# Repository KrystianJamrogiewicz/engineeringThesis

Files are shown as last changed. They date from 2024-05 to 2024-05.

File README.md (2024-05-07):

# Design and implementation of an unmanned aerial vehicle based on the ESP8266 microcontroller

The engineering thesis is based on the design and construction of an unmanned aerial vehicle in the form of a quadrocopter, using a microcontroller from the ESP8266 family. The theoretical part concerns the principle of operation of multicopters, and also presents the basic components from which they are built. The principles that guided the selection of individual components were discussed there. Next, the computer software that contributed to the project is described. The part devoted to the control system describes the aspects of designing and then implementing the electrical system, as well as the process of creating software controlling the system. The mechanical layout chapter focuses on designing and building the frame, putting all the components together, and testing the finished model. Finally, a partially working prototype of the unmanned aerial vehicle was created. The analysis of the results is discussed in the summary, as well as in the quadrocopter test section.

<p align="center"> drone photo </p>

Technologies:
- Arduino IDE
- C programming
- Autodesk Inventor
- Autodesk Eagle

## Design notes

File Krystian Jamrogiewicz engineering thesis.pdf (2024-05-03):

UNIWERSYTET RZESZOWSKI
Kolegium Nauk Przyrodniczych

Krystian Jamrogiewicz

Nr albumu: 114403

Mechatronika

Projekt i wykonanie bezzałogowego statku latającego w oparciu o mikrokontroler ESP32

Praca inżynierska

Praca wykonana pod kierunkiem

dr Mariusza Bestera

Rzeszów, 2023

## SPIS TREŚCI

## WSTĘP

Bezzałogowe statki latające już w latach trzydziestych XX wieku były określane przez

armię USA jako drony. Drony są sterowane zdalnie lub za pomocą zaprogramowanej

trajektorii. Aktualnie wykorzystywane są zarówno podczas obserwacji jak i wykonywania

różnych czynności w miejscach gdzie człowiek byłby narażony na niebezpieczeństwo [7].

Pierwszy bezzałogowy statek latający powstał w 1935 roku i był sterowany za pomocą

nadajnika radiowego. Dron szybko zainteresowało armię USA, początkowo konstrukcje

tego typu pełniły funkcję celów szkoleniowych dla obrony przeciwlotniczej. Z czasem

zaczęły pełnić funkcje samolotów, a ich zadaniem było zbieranie danych i fotografowanie

obszarów, do których bezpośredni lot załogowym samolotem lub helikopterem byłby

niemożliwy lub zbyt niebezpieczny [5, 7].

W Polsce formalnie drony określa się jako bezzałogowe statki latające (BSL), w

przestrzeni międzynarodowej wykorzystuje się częściej skrót UAV (z angielskiego:

Unmanned Aerial Vehicle) lub UAS (z angielskiego: Unmanned Aircraft System).

Podobnie jak większość zaawansowanych technologii, tak drony początkowo były

bardzo drogie w produkcji. Natomiast od kilku lat, dzięki dynamicznemu rozwojowi

elektroniki, zaczęły powstawać drony w formie wielowirnikowców. Wielowirnikowce w

celu uzyskania siły nośnej korzystają z wielu wirników (śmigieł). Dzięki możliwości

zawiśnięcia w powietrzu są stosowane głównie w celach fotograficznych, a także niekiedy

transportują lżejsze obiekty w trudno dostępne miejsca. Bezzałogowe statki latające w

formie wielowirnikowców w literaturze technicznej określa się również jako koptery lub

multikoptery, w tej pracy inżynierskiej będą wykorzystywane właśnie takie terminy [5, 10,

15].

## CEL I ZAŁOŻENIA PROJEKTU

Celem pracy inżynierskiej jest zaprojektowanie i wykonanie bezzałogowego statku

latającego w formie wielowirnikowca bazując na układzie ESP32. Praca będzie opierać się

na przedstawieniu teorii działania wielowirnikowca, dobraniu podzespołów potrzebnych

do jego wykonania, zaprojektowaniu i wykonaniu układu elektronicznego, a także

oprogramowania umożliwiającego zdalne sterowanie układem. Całość będzie dopełniona

o zaprojektowanie oraz wykonanie ramy multikoptera, rozmieszczeniu na niej wyżej

wymienionych elementów oraz przeprowadzeniu testów całości. Zakłada się wykonanie w

pewnym stopniu działającego prototypu bezzałogowego statku latającego, poznanie jego

możliwości, oraz przeanalizowanie uzyskanych wyników.

## 1. CZĘŚĆ TEORETYCZNA

Profesjonalnie produkowane wielowirnikowce są sterowane za pomocą fal

radiowych. Standardem zaczyna być technologia FPV (z angielskiego: First Person View)

umożliwia ona podgląd na żywo obrazu z kamery zamontowanej na multikopterze przy

użyciu np. smartfonu. Transmisja obrazu odbywa się za pośrednictwem radiowego

przesyłania danych. Klasyfikacja konstrukcji wielowirnikowców opiera się głównie o liczbę

ramion na których zamontowane są zespoły napędowe (silniki wraz ze śmigłami).

Najpopularniejsze z nich to: trikoptery – trzy zespoły napędowe kwadrokoptery – cztery

zespoły napędowe, heksakoptery – sześć zespołów napędowych [15, 16].

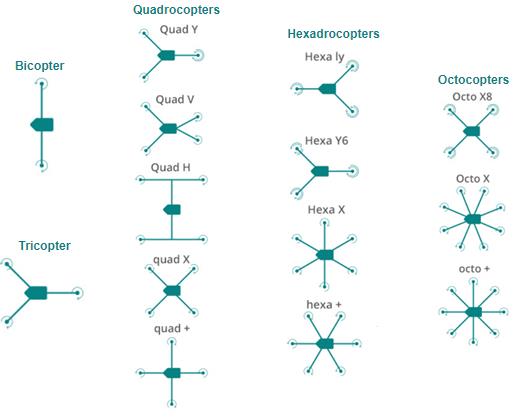
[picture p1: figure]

Rys. 1.1. Rodzaje konstrukcji wielowirnikowców [16]

Konstrukcja z większą liczbą ramion pozwala na bardziej stabilny lot, natomiast

podwójne zespoły napędowe montowane na mniejszej liczbie ramion (np. Y, X8) zwiększają

siłę ciągu, umożliwiając większy udźwig i ubezpieczając równoległy zespół napędowy na

wypadek awarii. Najbardziej rozpowszechnione są koptery w układzie X ponieważ

umożliwiają montaż kamery w miejscu o najlepszej widoczności [16]. Praca inżynierska

zostanie zrealizowana w oparciu o konstrukcje kwadrokoptera typu X

Aby w ogóle wielowirnikowiec był w stanie zawisnąć podczas lotu i nie obracać się w

niekontrolowany sposób wokół własnej osi stosuje się pary zespołów napędowych, które

obracają się w przeciwnych kierunkach, będzie to omówione szerzej w podrozdziale

dotyczącym śmigieł. W celu uzyskania kontrolowanego obrotu „yaw” należy zmniejszyć ciąg

powietrza dla jednej pary a zwiększyć dla drugiej, pozwala to na uzyskanie efektu obrotu

bez strat na wysokości. Podczas swobodnego zwisu wielowirnikowca konieczne jest takie

sterowanie ciągiem zespołów napędowych aby kompensowały one jego przechylenia. Zbyt

duże przechylenie doprowadzi do obrócenia się obiektu śmigłami w dół i jego upadku. Ruch

do przodu, do tyłu „pitch” oraz na boki „roll” jest realizowany poprzez przechylenie

kwadrokoptera w oparciu o zmniejszenie lub zwiększenie ciągu zespołów napędowych.

Przykładowo ruch do przodu odbędzie się poprzez zmniejszenie ciągu w przedniej części

multikoptera a zwiększenie w tylnej, uzyska się wtedy efekt pochylenia do przodu co

zapewni siłę pchającą skierowaną w kierunku pochylonej niżej strony. Cały proces

sterowania poszczególnymi zespołami napędowymi jest realizowany przez kontroler lotu.

Rys. 1.2. Kierunki obrotu śmigieł dla kwadrokopterów [17]

Rys. 1.3. Rodzaje ruchu dla kwadrokoptera typu + [17]

### 1.1. Środowisko sprzętowe

Ten podrozdział został poświęcony opisowi urządzeń oraz części wykorzystanych

podczas wykonania projektu inżynierskiego. Poruszone zostaną zasady wyboru poszczególnych podzespołów z uwzględnieniem ich parametrów technicznych. Znajdą się

w nim informację na temat: zespołów napędowych, regulatorów prędkości, kontrolera

lotu, urządzenia odczytującego położenie, oraz źródła zasilania.

### 1.1.1. Śmigła i silniki

Śmigła i silniki są głównymi systemami napędowymi multikoptera i odgrywają

decydującą rolę. Elementy te poddawane są największym obciążeniom spośród wszystkich

komponentów multikoptera. Z wszystkich podzespołów składających się na całość modelu

latającego parametry śmigieł oraz silników powinny zostać dobrane w pierwszej kolejności.

Aby wielowirnikowiec mógł poruszać się w powietrzu stosunek ciągu wszystkich zespołów

napędowych do masy całego obiektu powinien wynosić przynajmniej 2:1. Rozmiar śmigieł

decyduje o rozmiarze wielowirnikowca i to właśnie na nich spoczywa ciężar całej

konstrukcji [15].

Podstawową rolą śmigła jest wytwarzanie ciągu powietrza, czyli siły nośnej działającej w osi śmigła umożliwiającej unoszenie się modelu. Śmigło o większej średnicy będzie

generowało większą siłę nośną niż jego mniejszy odpowiednik przy tej samej prędkości

obrotowej. Cechą większych śmigieł jest większa masa i potrzeba zapewnienia większego

momentu obrotowego do ich napędzenia co skutkuje doborem mocniejszego silnika.

Większe śmigło generuje również większy nacisk na piastę za sprawą większej siły nośnej,

należy pamiętać aby wybierać śmigła możliwie dobrej jakości w celu uniknięcia pęknięcia

śmigła podczas jego wysokich obrotów. Zbyt małe śmigło powoduje częstą pracę silnika na

maksymalnych obrotach, natomiast zbyt duża powierzchnia łopat nadmiernie obciąża silnik

co prowadzi do braku możliwości uzyskania maksymalnego możliwego ciągu. Ilość łopat na

śmigle wpływa na ciąg w podobny sposób co jego średnica. Im więcej będzie łopat (tym

większa ich powierzchnia) tym większą siłę ciągu uda się uzyskać, jednak przełoży się to na

masę śmigła i zwiększone zużycie energii przez silnik. Zaletą takiego rozwiązania jest jednak

kompaktowość konstrukcji ponieważ śmigło o mniejszej średnicy z większą liczbą łopat

może pochwalić się podobnym ciągiem co jego większy odpowiednik z mniejszą ich ilością.

Kolejnym ważnym parametrem jest skok śmigła, można go porównać do skoku gwintu na śrubie. Ściśle zależy on od kąta pochylenia łopat śmigła jednak nie jest tym samym. Skok śmigła to odległość jaką pokonało by śmigło w powietrzu w czasie jednego obrotu gdyby

nie dochodziło do jego poślizgu. Analogicznie dla śruby będzie to odległość jaką pokona

wierzchołek śruby podczas wkręcania jej w gwint przez jeden pełny obrót. Parametry śmigła

podaje się za pomocą jego cechy czyli napisu widocznego na śmigle. Przykładowo

oznaczenie 1045 lub 10x4,5 oznacza, że śmigło ma średnice 10 cali i skok 4,5 cala [6, 12,

15].

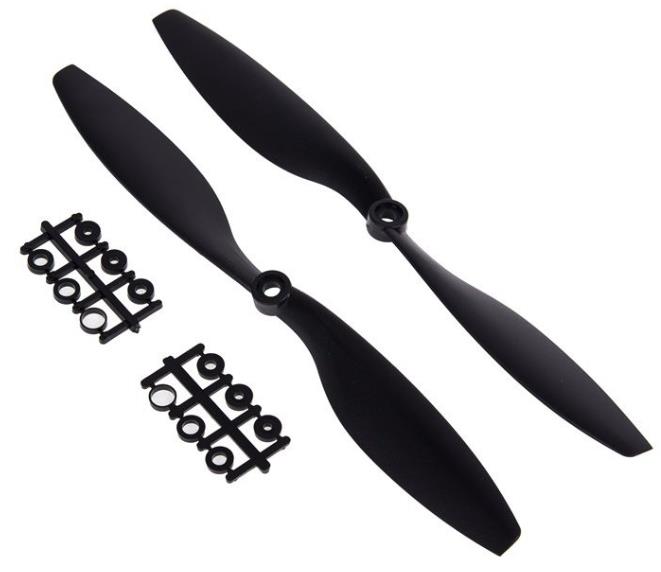
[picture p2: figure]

Rys. 1.4. Śmigła 1045 CW oraz CCW [18]

Podsumowując, im większe śmigło tym większy uzyskany ciąg, im większy skok śmigła

przy tej samej średnicy tym większa będzie prędkość modelu. Dla modelu akrobacyjnego

stosuje się śmigło o większym skoku ponieważ będzie on latał z większymi prędkościami,

modele przeznaczone do celów fotograficznych latające bardzo wolno, którym zależy na

dużej stabilności powinny mieć największą możliwą średnicę śmigła przy możliwie małym

skoku. Istnieje podział śmigieł na prawe oraz lewe, jest to spowodowane naturalnym

zjawiskiem obrotu całego koptera w kierunku ruchu śmigła. Aby pozbyć się tego efektu stosowane są pary silników obracające się w przeciwne strony co skutkuje koniecznością

posiadanie dwóch typów śmigieł, które w obydwu przypadkach muszą zapewnić ciąg

powietrza w odpowiednim kierunku. Wyróżniamy śmigła ciągnące (prawe) obracające się

zgodnie ze wskazówkami zegara oznaczone CW z angielskiego: Clockwise, lub R od regular. Śmigła pchające (lewe) kręcą się w lewą stronę posiadają oznaczenia CCW z angielskiego:

Counter Clockwise - przeciwnie do wskazówek zegara, oraz P – pusher [19].

Tab. 1.1. Zależność ciągu od parametrów śmigła [19]

Do materiałów z których wykonuje się śmigła zaliczamy: poliwęglan, nylon oraz

włókno szklane, oraz wszelkie ich mieszanki. W zależności od materiału użytego w produkcji

śmigła mogą być miękkie (poliwęglan, nylon) lub twarde (włókno szklane). Zaletą śmigieł

miękkich jest duża wytrzymałość na uderzenia, jednak trzeba liczyć się z ich odkształcaniem.

Natomiast śmigła twardsze mają dużo lepsze parametry dotyczące stabilności lotu i brak

jakichkolwiek ugięć, z kolei ich wadą jest możliwość łatwiejszego uszkodzenia podczas

upadku [6, 15, 19].

Silnik elektryczny zamienia energię elektryczną w energię mechaniczną, za pomocą

pola magnetycznego. W opisywanym projekcie ma za zadanie poruszyć śmigło z

odpowiednią prędkością w celu wytworzenia przez nie optymalnego ciągu powietrza. Silniki

wykorzystywane w kopterach dzielimy na szczotkowe oraz bezszczotkowe.

Odmiana szczotkowa często nazywana DC charakteryzuje się zasilaniem przez prąd

stały, zbudowana jest z: wirnika (rotoru), przez który przechodzi wyprowadzona na

zewnątrz oś, uzwojenia nawiniętego na wirnik, stojanu (statoru) zawierającego magnesy

stałe, który otacza wirnik, komutatora, który przełącza uzwojenia na wirniku, oraz

szczotek doprowadzających zasilanie do komutatora. Szczotki są elementem podlegającym

zużyciu na skutek tarcia, ponadto silniki szczotkowe mają mniejszą sprawność niż bez

szczotkowe. Sterowanie obrotami odbywa się poprzez zmianę napięcia zasilającego silnik

[9, 15].

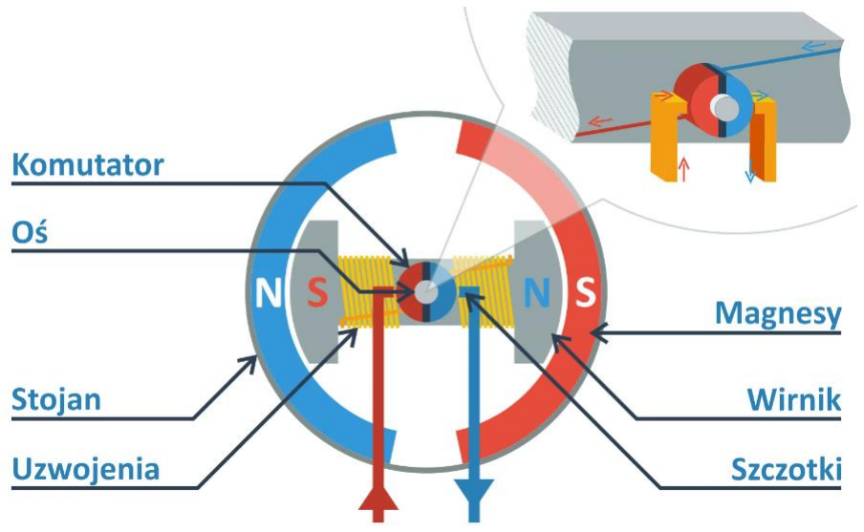
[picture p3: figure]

Rys. 1.5. Budowa silnika szczotkowego [9]

Odmiana bez szczotkowa BLDC jest zbudowana z wirnika (rotoru), na którym

zamocowane są magnesy oraz stojanu inaczej statoru, na którym znajdują się uzwojenia.

Rys. 1.6. Budowa silnika bez szczotkowego [4]

Na podstawie rozmieszczenia tych dwóch komponentów, silniki bez szczotkowe

dzielą się na inrunner „gdzie rotor jest otoczony przez stator” i outrunner „gdzie stator jest

otoczony przez rotor”. W wielowirnikowcach częściej stosowany jest typ outrunner, który

pozwala na uzyskanie większego momentu obrotowego [15].

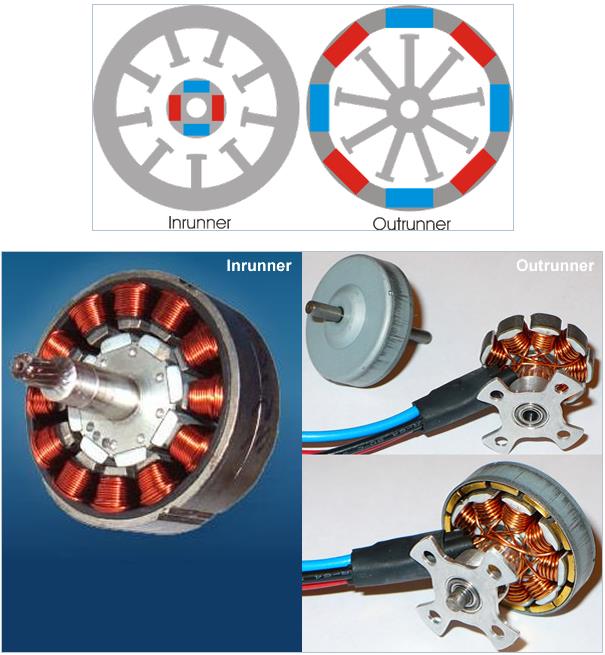
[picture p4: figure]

Rys. 1.7. Budowa silników Inrunner i outrunner [27]

Dzięki prostej budowie i nie posiadaniu elementów podatnych na zużycie silniki

bezszczotkowe górują nad wariantem szczotkowym za sprawą znacznie mniejszej

awaryjność, większej sprawności, oraz możliwością płynniejszej regulacji obrotów. W

konstrukcjach wielowirnikowych wykorzystywane są silniki zasilane prądem trójfazowym,

ich działanie jest niemożliwe bez komutatora którego rolę pełni osobna elektronika zwana

regulatorem ESC. Regulacja prędkości odbywa się przez zmianę częstotliwości przełączania

faz [15].

Najważniejszymi parametrami silnika są: napięcie zasilające podawane w woltach lub

za pomocą parametru S (zostanie omówione w podrozdziale poświęconemu zasilaniu),

maksymalny pobór prądu, maksymalna liczba obrotów na minutę, oraz liczba obrotów na

minutę uzyskana z jednego wolta napięcia zasilania oznaczana jako KV. Im mniejsza jest wartość parametru KV tym mniejsze są maksymalne obroty silnika, jednak rośnie wartość

momentu obrotowego. Dla większych śmigieł stosuje się silniki z mniejszym

współczynnikiem KV [15].

Aby poprawnie dobrać zespół napędowy (śmigło i silnik) należy skorzystać z

informacji dotyczących parametrów silnika najczęściej znajdujących się na stronie sklepu.

Kluczową informacją jest zakres dopuszczalnych rozmiarów śmigieł przewidziany dla tego

silnika.

Tab. 1.2. Parametry doboru śmigieł dla silnika A2212/13T 1000KV [20]

Silnikami i dla projektowanego koptera będą: A2212/13T 1000KV. Z dokumentacji

technicznej wynika, że dla tego typu silników optymalne będą śmigła o wymiarach w

zakresie od 8x4 do 10x8. Silnik powinien być zasilany napięciem 11,1V. Kolumny „Amps”

oraz „Thrust” w powyższej tabeli informują o maksymalnym poborze prądu, oraz

wytworzonym ciągu dla danej prędkości obrotowej oraz rozmiaru śmigła. Z uwagi na łatwą

dostępność dla tego projektu zostaną wybrane śmigła o oznaczeniu 1045.

Wybrany zespół napędowy będzie charakteryzował się: napięciem zasilania 11,1V

maksymalnym poborem prądu równym 13A, oraz maksymalnemu ciągowi około 750g. Z

uwagi na brak danych na temat śmigła o pożądanych wymiarach (1045) parametry zostały

oszacowane na podstawie śmigła (1050) o zbliżonych wymiarach. Dobrze dobrany zespół

napędowy powinien dysponować odpowiednim ciągiem i nie pobierać przy tym olbrzymich

ilości energii.

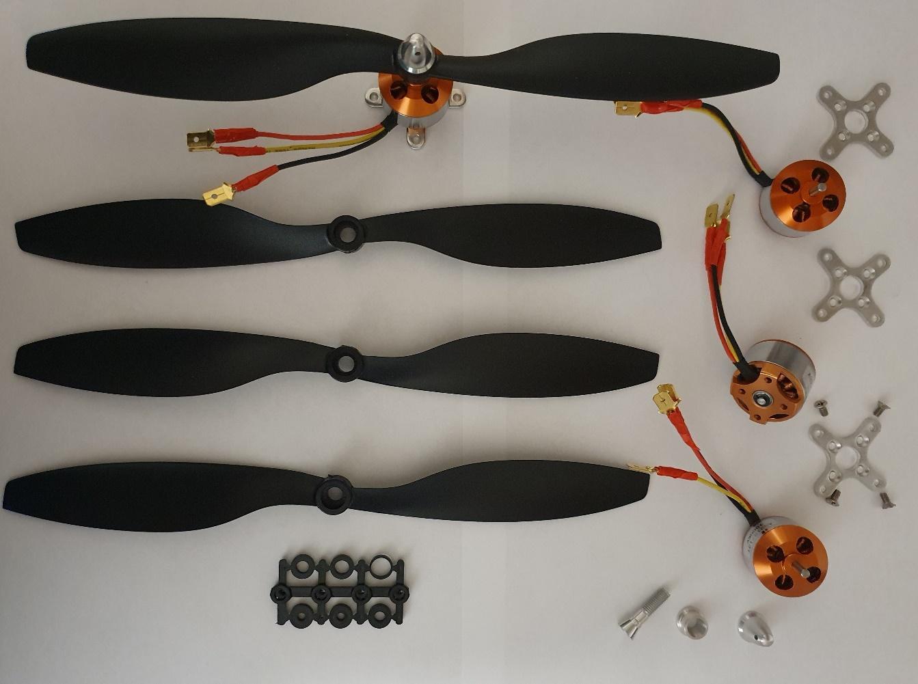
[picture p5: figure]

Rys. 1.8. Śmigła i silniki zastosowane w projekcie

### 1.1.2. Regulatory ESC

Elektroniczna kontrola prędkości ESC - z angielskiego: Electronic Speed Control. Zadaniem regulatorów ESC jest przekazanie energii z baterii do silnika. Na podstawie

sygnału sterującego PWM z kontrolera lotu regulator ESC przekazuje do silnika napięcie

które zapewni mu odpowiednią prędkość obrotową. Głównym podziałem regulatorów jest

ten ze względu na rodzaj obsługiwanego silnika: silniki szczotkowe (2 przewody zasilające

silnik) i silniki bezszczotkowe (3 przewody zasilające silnik). Niektóre Regulatory ESC

posiadają możliwość zasilania urządzeń mniejszym napięciem niż to z baterii, przykładowo

gdy napięcie baterii jest większe niż 6V można zasilać płytkę kontroli lotu napięciem 5V z

odpowiedniego wyprowadzenia regulatora ESC. Regulator który to umożliwia posiada

obwód eliminatora baterii zwany BEC - Battery Elimination Circuit. Kolejnym ważnym

parametrem jest napięcie pracy często wyrażane w liczbie ogniw baterii np.: 2S, 3S, 4S. Ten

aspekt zostanie szerzej omówiony w części poświęconej zasilaniu. Do wcześniej wybranych

śmigieł i silników należy dobrać regulatory ESC o odpowiednim prądzie pracy. Zbyt słaby

regulator może ulec uszkodzeniu, zbyt mocny regulator nie przynosi negatywnego efektu

poza większą wagą i ceną. Regulator powinien być tak dobrany aby jego prąd pracy był o

około od 20% do 30% większy od maksymalnego prądu pobieranego przez silnik z

uwzględnieniem wielkości śmigła. Jeżeli silnik często jest blokowany lub w pełni obciążony

(na przykład w samochodach RC) zalecane jest dobranie regulatora o prądzie pracy bliskim

prądowi szczytowemu silnika [15, 21, 22].

Rys. 1.9. Zastosowany (https://cf.shopee.com.my/file/10e4f0d7d5f3a03d9d0fc844b3e10bfa) w projekcie regulator ESC [23]

Podczas wykonywania tego projektu wybrano regulatory ESC: Brushless 30A 2-4S.

Regulator tego typu może pracować z ciągłym prądem równym 30A i prądem szczytowym

równym 40A. Posiada BEC - możliwość zasilania innych podzespołów napięciem 5V z

maksymalnym prądem 2A. Może pracować z akumulatorami od 2S do 4S.

### 1.1.3. Kontroler lotu

Kontroler lotu jest poniekąd „mózgiem” modelu, który odpowiada za jego

prawidłowe reakcje na wydawane mu polecenia sterujące, oraz czynniki zewnętrzne takie

jak podmuchy wiatru. Dzięki danym wejściowym: pochyleniom i przyspieszeniom

(względem osi: x, y, z), zaprogramowany algorytm kontrolera lotu wyznacza orientacje

multikoptera w przestrzeni. W następnej kolejności ustala odpowiednie prędkości

poszczególnych silników. Profesjonalne kontrolery lotu składają się z mikroprocesora,

żyroskopu i akcelerometru na jednej kompaktowej płytce. Bardziej zaawansowane

konstrukcje posiadają również dodatkowe czujniki i systemy jak: kompas magnetometr,

barometr. Mikroprocesor płytki kontroli lotu powinien być wystarczająco szybki aby podołać wielu skomplikowanym obliczeniom w możliwie najkrótszym czasie. Wolne

procesory mogą być przyczyną nadmiernych korekt podczas lotu [10, 15].

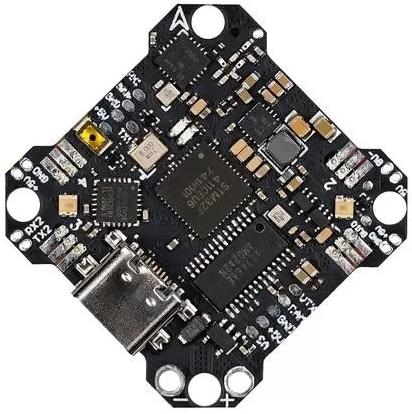
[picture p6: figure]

Rys. 1.10. Kontroler lotu F4 1S 12A AIO V2 (ELRS 2.4G) – BETAFPV [20]

Układ ESP8266 osadzony w płytce NodeMCU v2 jest przykładem mikrokontrolera z

możliwością sterowania sygnałem WiFi. W omawianym projekcie będzie on spełniał funkcję

kontrolera lotu.

ESP8266 jest układem SoC (z angielskiego: System on a Chip) od chińskiego

producenta Espressif Systems. Układ zawiera w sobie elementy niezbędne do komunikacji

przez WiFi w standardzie 802.11 b/g/n pracujących z częstotliwością 2,4 GHz. Posiada

również | wbudowany | stos TPC/IP i | może | działać | w | trybach AP (Access

Point), STA (standalone) oraz AP+STA [2, 8].

NodeMCU v2 jest płytką, która wykorzystuje układ ESP8266 w postaci 22 pinowego

modułu z wbudowanym 32-bitowym układem RISC taktowanym zegarem 80MHz.

Układ wyróżnia się 10 portami GPIO, 2 portami UART oraz jednym 10-bitowym wejściem ADC. Każdy z portów GPIO może być wykorzystany jako PWM, I²
| | | | | | c, SPI lub 1-Wire.

Moduł NodeMCU v2 został wyposażony w stabilizator napięcia 3,3V oraz konwerter USB-

to-UART CP2120, dzięki czemu jest możliwe zasilenie i programowanie płytki bezpośrednio

z portu USB. Programowanie płytki może odbywać się za pomocą języka

skryptowego Lua lub przy pomocy Arduino IDE [2, 8].

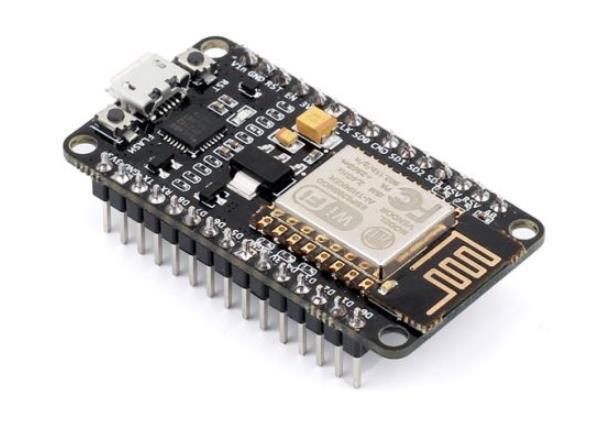
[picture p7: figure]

Rys. 1.11. Płytka NodeMCU v2 [8]

Dane techniczne:

- Moduł zbudowany w oparciu o układ ESP8266-12E z anteną PCB
- Łączność Wi-Fi w standardzie 802.11 b/g/n
- Działa w trybach AP (Access Point), STA (Standalone), AP+STA
- Obsługuje TKIP, WEP, CRC, CCMP, WPA/WPA2, WPS
- Zasilanie: 4,5V - 10V (lub 5V przez port USB)
- Maksymalny pobór prądu: 215mA
- Procesor RISC 80MHz
- 10 portów GPIO - PWM / I2C / SPI / 1-Wire
- Maksymalne natężenie na portach I/O: 12mA
- Konwerter USB-UART - CP2102
- Konwerter ADC - 10-bitowy
- 30 portów w rastrze 2,54mm
- Złącze micro USB
- Wymiary: 49 x 25mm

- Dwa przyciski: FLASH, służący do programowania, oraz RST (RESET)
- Niebieska dioda LED podłączona do GPIO16

Rys. 1.12. Opis wyprowadzeń płytki NodeMCU v2 [28]

### 1.1.4. Żyroskop i akcelerometr

Orientacja multikoptera określa jego pochylenie, przechylenie i odchylenie. Czujniki

potrafiące odczytać orientację to akcelerometry i żyroskopy. Są one umieszczane w taki

sposób, aby mogły mierzyć ruch we wszystkich trzech płaszczyznach. Akcelerometry

odczytują przesunięcia wzdłuż trzech poszczególnych osi (x, y, z, nazywane też

translacjami), podczas gdy żyroskopy mierzą obroty wokół osi pochylenia, przechylenia i

odchylenia. System sterowania powinien być jak najszybszy i najczulszy, aby w porę mógł

zareagować np. na gwałtowny podmuch wiatru. Optymalny efekt można uzyskać stosując

zarówno żyroskop jak i akcelerometr. [10, 15].

Istnieją dwa typy akcelerometrów: piezoelektryczne i pojemnościowe.

Akcelerometry piezoelektryczne są spotykane najczęściej. Zawierają one mikroskopijne

kryształy, które reagują na nacisk, gdy struktura kryształu zostanie odkształcona,

generowany jest prąd elektryczny. Mierząc polaryzację i wielkość tego prądu, system sterowania może ustalić kierunek i prędkość ruchu. W akcelerometrach pojemnościowych

mierzona jest pojemność elektryczna między mikrostrukturami znajdującymi się blisko

czujnika. W miarę jak mikrostruktury te zbliżają się lub oddalają od czujnika, zmienia się

pojemność. Mierząc ją, system sterowania może określić kierunek i prędkość ruchu [15].

Istnieje również kilka rodzajów żyroskopów: kryształowe (których działanie jest

zbliżone do akcelerometrów piezoelektrycznych), ceramiczne (w których wykorzystywane

są miniaturowe ceramiczne kolumny lub pryzmaty) i silikonowe (których budowa różni się

w zależności od producenta) [15].

W projekcie został wykorzystany moduł żyroskopu z akcelerometrem MPU6050.

Zamontowany na płytce modułu układ scalony MPU6050 zawiera struktury MEMS (z

angielskiego: Micro Electro Mechanical Systems) pełniące funkcję półprzewodnikowych

żyroskopów i akcelerometrów. Czujniki układu odgrywające rolę akcelerometrów mierzą

wartość przyspieszenia w 3 osiach, a czujniki żyroskopów mierzą rotację względem tych osi.

Gdy moduł jest ustawiony poziomo i pozostaje w bezruchu, akcelerometr osi Z powinien zmierzyć wartość około 9,81 m/s²
co odpowiada średniemu przyspieszeniu ziemskiemu, natomiast akcelerometry osi X i Y powinny podawać wartości bliskie 0 m/s²
. Odwrócenie

płytki „do góry nogami” skutkuje odczytem wartości ujemnej – 9,81 m/s²
zmierzonej w osi
Z. Każde przesunięcie płytki np. w kierunku +X spowoduje pomiar w tej osi chwilowego

przyspieszenia o wartości dodatniej, proporcjonalnego do prędkości ruchu płytki. Z kolei

w czasie obracania płytki wokół osi żyroskopy zmierzą obrót w jednostkach stopni

kątowych na sekundę [13, 25].

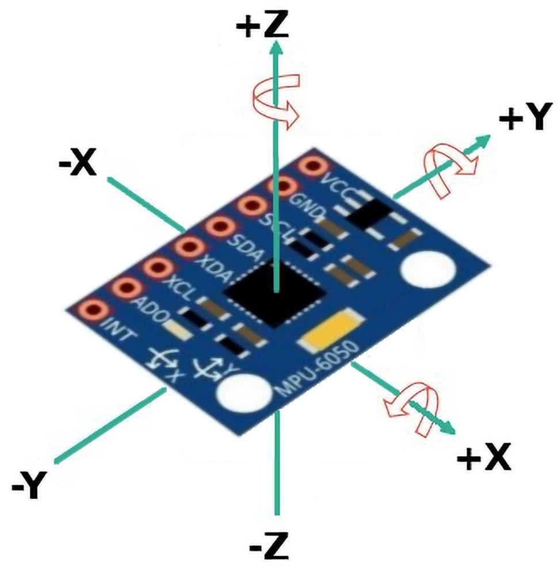
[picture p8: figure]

Rys. 1.13. Opis osi dla modułu MPU6050 [13]

Płytka jest wyposażona w układ stabilizatora LDO pozwalający rozszerzyć

dopuszczalne napięcie zasilania do zakresu 3,3V - 5V. Charakteryzuje się niskim poborem

prądu do około 350µA. Dodatkowo na płytce zamontowano oporniki podciągające linie magistrali I²C do napięcia zasilającego oraz opornik ustawiający na wyprowadzeniu wyboru

adresu AD0 poziom niski. Uzyskiwane w czasie pomiarów sygnały analogowe

akcelerometrów i żyroskopów są poddawane obróbce w wewnętrznych przetwornikach

ADC i jako wartości cyfrowe są dostępne do odczytu z rejestrów układu MPU6050. [13].

Oznaczenia i funkcje wyprowadzeń:

- VCC – napięcie zasilające 3,3...5 V
- GND – masa zasilania
- SCL – linia zegarowa magistrali I2C podciągnięta do VCC
- SDA – linia danych magistrali I2C podciągnięta do VCC
- XDA – linia danych dodatkowej niezależnej magistrali I²C
- XCL – linia zegara dodatkowej niezależnej magistrali I²C
- ADO – wejście wyboru adresu, na który będzie reagował moduł w obrębie głównej magistrali I²C (dla poziomu niskiego będzie to adres 0x68, dla poziomu wysokiego (3,3 V) 0x69. Linia jest podciągana do poziomu niskiego poprzez opornik na płytce modułu)

- INT – wyjście przerwania, może być zaprogramowana do wystawiania stanu niskiego w przypadku wystąpienia zdarzenia np. przekroczenia poziomu przyspieszenia

### 1.1.5. Zasilanie

Istnieje wiele typów akumulatorów jednak multikoptery najczęściej są zasilane za

pomocą wariantów litowo polimerowych (Li-Po). Ten typ akumulatora ma najlepszy

stosunek masy do energii jaką magazynuje. Składa się z jednego lub kilku połączonych

ogniw (cel). Ogniwo Li-Po jest zbudowane ze stopów litu i polimerów o właściwościach

przewodzących, zwykle w postaci stałej lub żelu, jak standardowe ogniwa posiada anodę

oraz katodę. Napięcie pracy pojedynczego ogniwa mieści się w zakresie od 2,75V do 4,2V.

Do poprawnej eksploatacji akumulatora Li-Po niezbędne będzie używanie specjalnych

ładowarek z balanserem, które dostarczają takie samo napięcie do każdego ogniwa, należy

pamiętać, by ładowarka nie ładowała akumulatora prądem większym niż jego maksymalny

prąd ładowania. Aby cieszyć się długim działaniem akumulatora nie należy dopuszczać do

rozładowania się pojedynczych ogniw poniżej napięcia 3V. W celu długotrwałego

przechowywania akumulatora należy naładować pojedyncze ogniwa do napięcia od 3,7V

do 3,8V [15].

Rys. 1.14. Akumulator zastosowany w projekcie [29]

Napięcie znamionowe jest podstawowym parametrem akumulatora, jego wielkość

musi mieścić się w zakresie napięć obsługiwanych przez silniki. Jest podawane w woltach,

lub za pomocą parametru S. Liczba stojąca przed S określa z ilu ogniw (cel) składa się

akumulator, przykładowo 3S oznacza, że akumulator jest zbudowany z 3 ogniw. Biorąc pod

uwagę, że napięcie znamionowe jednego ogniwa wynosi 3,7V to akumulator 3S będzie miał

napięcie znamionowe równe: 3 × 3,7V = 11,1V [15].

Pojemność akumulatora wyrażona w mAh (miliamperogodzinach) określa jak duży

prąd przez określony czas można pobrać z w pełni naładowanego akumulatora aby go w

pełni rozładować. Im większa pojemność tym akumulator będzie mógł dłużej zasilać

odbiorniki, jednak wraz ze wzrostem pojemności zwiększają się rozmiary i masa

akumulatora [15].

Wydajność prądowa, określana parametrem C jest to maksymalne natężenie prądu

jakie można pobrać z akumulatora. Oblicza się ją poprzez mnożenie liczby stojącej przed C

oraz pojemności akumulatora. Przykładowo akumulator o pojemności 2200mAh i

oznaczeniu 30C będzie cechował się następującą wydajnością prądową:

Zamiana na jednostki SI: | 2200mAh = 2,2Ah
Wydajność prądowa: | 2,2Ah × 30 = 66A

Stosuje się także oznaczenia np.: 30C-40C, pierwsza cyfra (30) to współczynnik dla ciągłej

wydajności prądowej, a druga (40) dla chwilowej, co oznacza, że przez krótką chwilę

akumulator może osiągnąć większą wydajność prądową bez jego uszkodzenia [15].

Dobrze dobrany akumulator musi być w stanie zaspokoić zapotrzebowanie prądowe

dla wszystkich zespołów napędowych oraz innych podzespołów multikoptera. Zbyt mała

wydajność prądowa doprowadzi do uszkodzenia akumulatora oraz nie uzyskania

maksymalnego możliwego ciągu przez zespół napędowy.

Parametry odbiorników:

Zespół napędowy:

Napięcie zasilania silnika: 11,1V

Maksymalny pobór prądu dla jednego silnika: 13A

Maksymalny pobór prądu dla wszystkich silników: 13A × 4 = 52A

Kontroler lotu:

Napięcie zasilania: 4,5V – 10V

Maksymalny pobór prądu = 215mA = 0,215A

Żyroskop / akcelerometr:

Napięcie zasilania: 3,3V – 5V

Maksymalny pobór = 350µA = 0,00035A

Maksymalny pobór prądu całego układu = 52A + 0,215A + 0,00035A = 52,21535A

Napięcie zasilania całego układu będzie wynosić 11,1V ponieważ właśnie takiego

wymagają silniki, Kontroler lotu oraz żyroskop / akcelerometr będą zasilane napięciem 5V

przekonwertowanym z 11,1V przez regulatory ESC.

Maksymalny pobór prądu całego układu będzie wynosił około 52,21535A. Dla

bezpieczeństwa wydajność prądowa akumulatora powinna być przynajmniej 1A większa niż

obliczony pobór całego układu. Znając maksymalny pobór prądu można oszacować czas

lotu. Teoretycznie dla akumulatora o pojemności 2200mAh obciążenie pobierające prąd

2200mA rozładuje go w pełni po upływie godziny. Jednak w praktyce akumulatory Li-Po aby

nie doznać uszkodzenia nie mogą być rozładowywane poniżej 20% ich pojemności.

Szacowanie czasu pracy dla obciążenia 53A i pojemności 2200mAh:

Pojemność akumulatora = 2200mAh = 2,2Ah

Zmniejszenie pojemności o 20%: 2,2 × 0,8 = 1.76Ah

Czas pracy akumulatora wyraża się wzorem:

t = Cp / Ir

gdzie:

t – czas pracy w godzinach

Cp – pojemność akumulatora

Ir – prąd pobierany przez odbiorniki

Cp = 1,76Ah

Ir = 53A

t = 1,76Ah / 53A = 0.0332075471698113h ≈ 120s = 2min

Czas pracy podczas poboru 53A wynosi 2 min. Należy pamiętać, że przyjęty pobór

prądu jest oszacowany dla silników kręcących się z maksymalną prędkością, a czas

przeciętnego lotu powinien potrwać nieco dłużej. Aby dokładniej oszacować czas lotu

należy obliczyć uśrednioną wartość poboru prądu.

Wybór odpowiedniego akumulatora dla projektu:

Wymagany będzie akumulator o napięciu znamionowym 11,1V i wydajności

prądowej większej niż 53A. Dla danego układu zastosowane będzie źródło zasilania typu Li-

Po firmy Redox o oznaczeniach: 3S 2200mAh 30C. Posiada ono napięcie znamionowe 11,1V,

pojemność 2200mAh, oraz wydajność prądową równą 66A. Jego masa to 150 g a wymiary:

103 x 34 x 20 mm. Oszacowany czas lotu na jednym ładowaniu będzie nie mniejszy niż 2

minuty. Dla projektu o tych parametrach bardziej zalecany byłby akumulator o większej

pojemności zapewniający dłuższy czas lotu, jednak z powodu dostępności oraz testowego

przeznaczenia projektu zostało wybrane po wyższe źródło zasilania.

### 1.2. Środowisko programowe

W tym podrozdziale zostały omówione oprogramowania oraz aplikacje wykorzystane

podczas wykonania pracy inżynierskiej. Znajdą się w nim informację na temat

oprogramowania służącego do programowania mikrokontrolerów, aplikacji która posłużyła

do sterowania urządzeniem, a także programów używanych do projektowania obwodu

elektrycznego, oraz modelowania 3D.

### 1.2.1. Arduino IDE

Arduino IDE (z angielskiego: Integrated Development Environment) jest otwartym

środowiskiem programistycznym, które upraszcza proces pisania kodu i pozwala przesłać

go na płytki z rodziny Arduino. Otwarty kod źródłowy - open source umożliwia ciągłe

udoskonalanie środowiska przez osoby które z niego korzystają. Oprogramowanie jest

także open hardware – otwarte sprzętowo co oznacza, że można je stosować na dowolnej

płytce która została wykonana zgodnie ze standardem Arduino [11]. Oprogramowanie

można pobrać ze strony: https://www.arduino.cc/en/software [dostęp: 31.01.2023 r.].

Oprogramowanie to posłużyło do zaprogramowania modułu NodeMCU v2 aby

spełniał on funkcję kontrolera lotu. W tym celu należało odpowiednio skonfigurować

środowisko Arduino IDE. Podczas wykonywania omawianego projektu korzystano z

Arduino IDE 1.8.18.

Pierwszym zabiegiem jest otworzenie zakładki: „File -> Preferences” a następnie w

polu: | „Additional | Boards | Manager | URLs” | wpisać | link:

http://arduino.esp8266.com/staging/package_esp8266com_index.json [8].

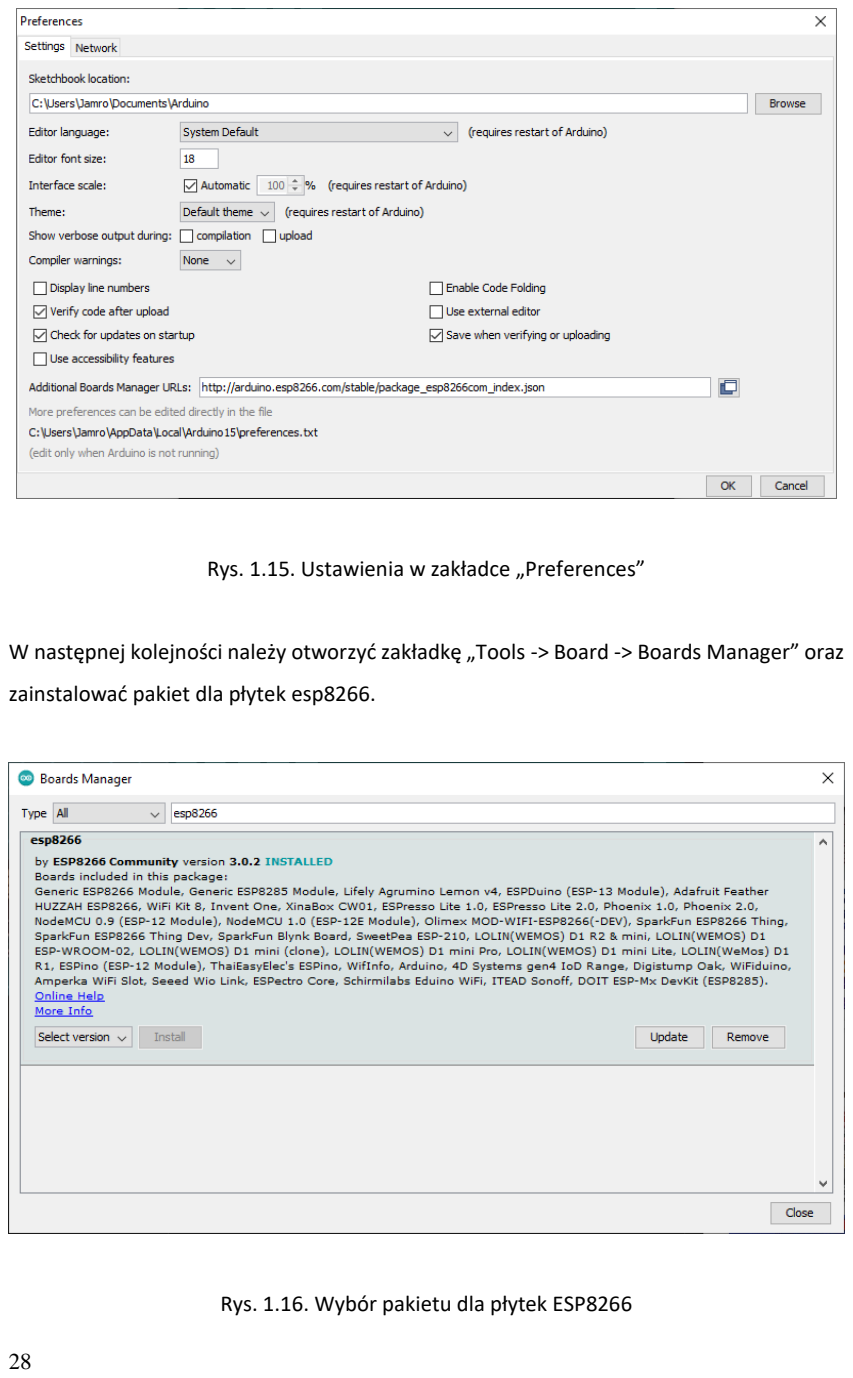
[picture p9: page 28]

Rys. 1.15. Ustawienia w zakładce „Preferences”

W następnej kolejności należy otworzyć zakładkę „Tools -> Board -> Boards Manager” oraz

zainstalować pakiet dla płytek esp8266.

Rys. 1.16. Wybór pakietu dla płytek ESP8266

Ostatnim krokiem jest wybór płytki NodeMCU 1.0 (ESP12-E Module) w zakładce:”Tools ->

Board -> ESP8266 Boards (3.0.2). Po wyborze odpowiedniej płytki należy ustawić resztę

parametrów tak jak na poniższym zdjęciu oraz wybrać odpowiedni port usb.

Rys. 1.17. Wybór odpowiedniej płytki wraz z jej ustawieniami.

Do prawidłowego działania systemu konieczne jest zainstalowanie sterownika CH340. Po

wykonaniu tych wszystkich czynności płytkę NodeMCU v2 można będzie programować w

środowisku Arduino IDE za pomocą składni języka obsługiwanej przez klasyczną płytkę

Arduino [13].

### 1.2.2. Aplikacja sterująca

Do sterowania zaprojektowaną konstrukcją posłużyła aplikacja o nazwie:

„NodeMCU_Car” udostępniona przez twórców kanału na YouTube o nazwie „Pro Know”.

Aplikacja jest dostępna na urządzenia z androidem, można ją pobrać ze strony:

https://drive.google.com/drive/folders/1DwreeBjJxSEnlHIfhAz_XfE8erKbKwk

[dostęp: 31.01.2023 r.].

Do komunikacji z kontrolerem lotu wykorzystuje sygnał WiFi którego źródłem jest

układ ESP8266. Aby połączyć telefon z multikopterem należy wyszukać odpowiednią sieć

WiFi i się z nią połączyć. Interfejs aplikacji posiada 9 przycisków monostabilnych oraz suwak

o 10 położeniach podtrzymujący sygnał ostatnio ustawionej pozycji.

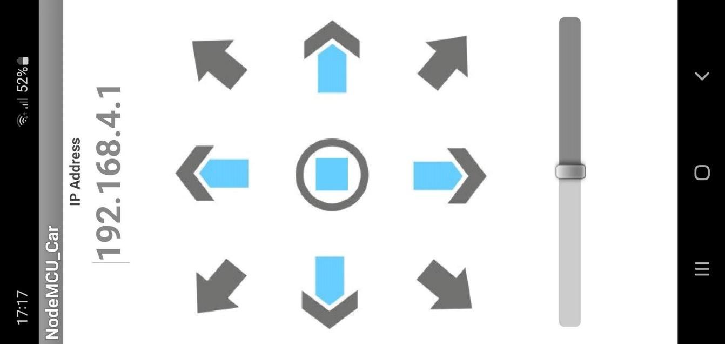
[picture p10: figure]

Rys. 1.18. Interfejs aplikacji

Działanie aplikacji polega na wysyłaniu do modułu ESP8266 komend które są przypisane do

odpowiedniego przycisku i pozycji suwaka.

Tab. 1.3. Komendy wysyłane przez interfejs [opracowanie własne]

Symbol | Komenda
Strzałka w górę | F
Strzałka w dół | B
Strzałka w prawo | R
Strzałka w lewo | L
Strzałka w górę i prawo | I
Strzałka w górę i lewo | G
Strzałka w dół i prawo | J
Strzałka w dół i lewo | H
Przycisk na środku | S
Suwak w pozycji 0 | 0
Suwak w pozycji 1 | 1
Suwak w pozycji 2 | 2
Suwak w pozycji 3 | 3
Suwak w pozycji 4 | 4
Suwak w pozycji 5 | 5
Suwak w pozycji 6 | 6
Suwak w pozycji 7 | 7
Suwak w pozycji 8 | 8
Suwak w pozycji 9 | 9

Podczas projektowania multikoptera zdecydowano, że bardziej ergonomicznym

rozwiązaniem będzie używanie interfejsu sterującego w pozycji poziomej tak jak na

załączonym powyżej zdjęciu. Odwrócenie przycisków zostało uwzględnione w poniższej

tabeli.

Tab. 1.4. Elementy interfejsu zastosowane w projekcie [opracowanie własne]

Funkcja | Symbol | Komenda
Lot do przodu | Strzałka w prawo | R
Lot do tyłu | Strzałka w lewo | L
Lot w prawo | Strzałka w dół | B
Lot w lewo | Strzałka w górę | F
Obrót w prawo | Strzałka w dół i prawo | J
Obrót w lewo | Strzałka w góra i prawo | I

Suwak będzie odpowiadał za sterowanie prędkością obrotową silników. Położenie 0 będzie

oznaczało, że silniki są wyłączone, natomiast 9 oznacza maksymalną ich prędkość.

Położenia pomiędzy będą w możliwie płynny sposób odpowiadały za prędkości pomiędzy

zerem a maksimum.

### 1.2.3. Autodesk Eagle

Autodesk Eagle jest to oprogramowanie komputerowe przeznaczone do

wspomagania projektowania obwodów elektronicznych. Zostało stworzone przez firmę

CadSoft a obecnie jest rozwijane przez Autodesk. Posiada edytor schematów oraz płytek

drukowanych, a także bogatą bibliotekę elementów elektrycznych. Umożliwia modyfikację

wielu parametrów, ważniejsze z nich to: szerokość ścieżki oraz kąt jej zagięcia. Przydatna

okazuje się siatka wymiarowa pomagająca w dokładnym rozmieszczeniu elementów na

płytce, a także poznaniu jej całkowitych wymiarów. Funkcja tworzenia tekstu daje

możliwość opisu danych elementów, co pomaga w orientacji w trakcie podglądu, istnieje

także możliwość naniesienia tekstu na wykonywaną płytkę. Podstawową wersję tego

oprogramowania można pobrać za darmo ze strony Autodesk:

https://www.autodesk.com/products/eagle/free-download [dostęp: 31.01.2023 r.].

Podczas wykonywania pracy inżynierskiej oprogramowanie Autodesk Eagle 9.6.2

zostało zastosowane do zaprojektowania płytki PCB dla kontrolera lotu oraz urządzenia

odczytującego orientacje bezzałogowego statku powietrznego. Płytka umożliwia proste połączenie elektryczne podzespołów, ich zasilanie, przekaz sygnału sterującego, a także co

ważne daje możliwość ich stabilnego umocowania.

Rys. 1.19. Zaprojektowana płytka PCB

### 1.2.4. Autodesk Inventor

Autodesk Inventor to oprogramowaniem typu CAD rozpowszechnione przez firmę

Autodesk. Jest parametrycznym system projektowania w przestrzeni trójwymiarowej (3D)

z podsystemem automatycznego generowania dokumentacji dwuwymiarowej (2D),

umożliwiający stosowania również techniki projektowania adaptacyjnego. Dzięki

oprogramowaniu można projektować części 3D, łączyć je w zespoły, przeprowadzać ich

analizy wytrzymałościowe, tworzyć dokumentację techniczną a także animacje.

Typowy algorytm parametrycznego adaptacyjnego projektowania 3D wygląda

następująco:

- Modelowanie niezależne części lub modelowanie ich od razu z poziomu zespołu.
- Modelowanie zespołu.
- Redagowanie parametrycznie sprzężonej z modelami dokumentacji zespołu pod różnymi postaciami (klasyczne rzuty na płaszczyźnie, widoki i animacje montażu i demontażu itp.).
- Parametryczna adaptacyjna modyfikacja projektu z poziomu modeli lub rysunków.

Autodesk Inventor tworzy przede wszystkim modele hierarchiczne, których elementem jest

sekwencyjne drzewo historii operacji znajdujące w przeglądarce obiektów [1].

Podczas wykonywania bezzałogowego statku powietrznego oprogramowanie

Autodesk Inventor Professional 2023 posłużyło do zaprojektowania ramy multikoptera.

Oprogramowanie to jest płatne jednak firma Autodesk dysponuje darmową licencją

dostępną dla osób posiadających status studenta. Można je pobrać ze strony producenta:

https://www.autodesk.pl/products/inventor/overview?term=1-YEAR&tab=subscription

[dostęp: 31.01.2023 r.].

## 2. UKŁAD STEROWANIA

Układ sterowania odpowiada za odpowiednią reakcję multikoptera na przekazywany

mu sygnał z interfejsu sterującego. Składa się zarówno z elementów elektronicznych jak i

sterującego nimi algorytmu. W tym rozdziale został omówiony aspekt zaprojektowania oraz

wykonania układu elektrycznego a także jago odpowiedniego zaprogramowanie. Aby układ

sterowania działał zgodnie z założeniem zostały przeprowadzone symulacje do których

posłużyła płytka stykowa.

### 2.1. Połączenie elementów elektronicznych

Ten podrozdział został poświęcony sposobowi połączenia wcześniej wybranych

elementów elektronicznych według zaprojektowanych schematów. Omówione w nim są

poszczególne kroki wykonywane podczas dążenia do ostatecznej wersji układu oraz

napotkane problemy.

W początkowej fazie projektu układ elektryczny został zbudowany na płytce

stykowej. Do jego wykonania posłużyły: płytka stykowa, NodeMCU v2, MPU6050, diody

symulujące działanie zespołów napędowych, oraz rezystory konieczne do działania diod.

Cały układ był zasilany z płytki NodeMCU v2 napięciem 3,3V która z kolei była zasilana

napięciem 5V z portu USB. Do portów D1 oraz D2 został podłączony moduł MPU6050, do

portów D5, D6, D7, D8 zostały podłączone diody. Całość bardzo dobrze sprawdziła się

podczas tworzenia algorytmu sterującego. Diody były zasilane sygnałem PWM, który

zależał od sygnału z interfejsu sterującego, oraz pochylenia całego układu odczytywanego

przez moduł MPU6050. Poziom światła jakie wytwarzały diody symulował prędkość

obrotową poszczególnych zespołów napędowych.

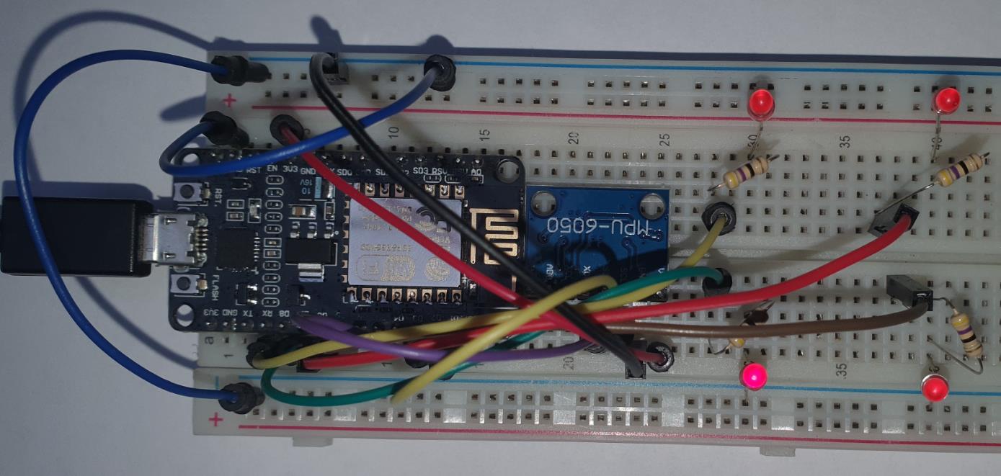
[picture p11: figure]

Rys. 2.1. Układ elektryczny wykonany na płytce stykowej

Po uzyskaniu optymalnego efektu na diodach zostały one zastąpione docelowymi

regulatorami ESC do których podłączono silniki bez szczotkowe oraz źródło zasilania 11,1V.

Wykonując ten zabieg napotkano na problem braku reakcji silników na sygnał sterujący,

miał na to wpływ fragment kodu oraz rozdzielczość sygnału PWM co zostało omówione w

następnym podrozdziale. Po poprawieniu kodu okazało się, że silniki których sygnał

sterujący jest podawany z portów D7 oraz D8 nadal nie działają. Powodem tego zjawiska

okazał się być tryb działania tych portów, problem rozwiązano poprzez wyprowadzenie

sygnału sterującego silnikami z portów D0 oraz D3. Po wykonaniu tych operacji układ zacząć

działać poprawnie. W ten sposób została zaprojektowana ostateczna wersja schematu

elektrycznego.

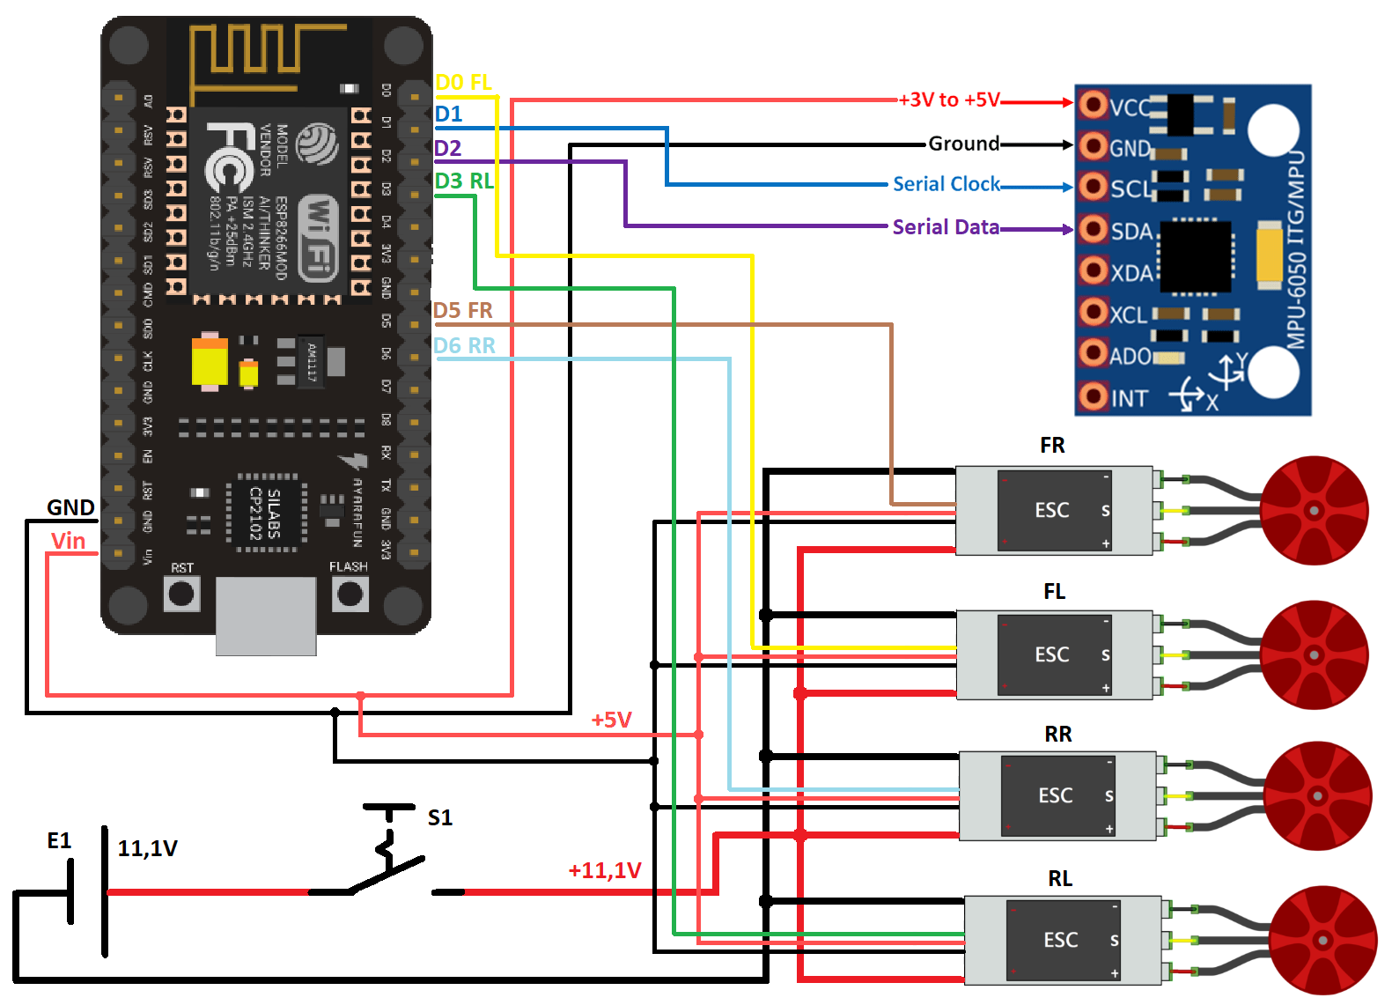
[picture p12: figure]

Rys. 2.2. Schemat układu elektrycznego

Aby w ergonomiczny sposób wykorzystać przestrzeń zdecydowano się na

zaprojektowanie oraz wykonanie płytki PCB zgodnie z powyższym schematem. Projekt

został wykonany w programie Eagle. Zaprojektowana płytka posiada gniazda montażu

NodeMCU v2 oraz MPU6050, a także wyprowadzenia umożliwiające przekazywanie

sygnału sterującego oraz jej zasilanie. Dodano także wyprowadzenie pozwalające na

montaż anteny zewnętrznej.

Rys. 2.3. Zaprojektowana płytka PCB, widok dolnej warstwy

Rys. 2.4. Zaprojektowana płytka PCB, widok na górną i dolną warstwę

Z powodu łatwej dostępności i czasu realizacji płytka została wykonana na bazie płytki

uniwersalnej.

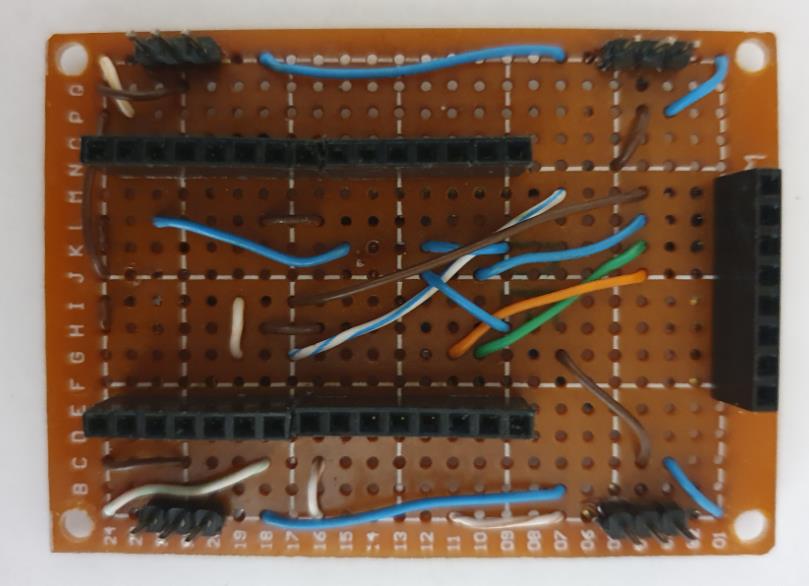
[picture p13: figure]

Rys. 2.5. Wykonana płytka PCB

Wykonana płytka PCB umożliwiła stabilne osadzenie układów NodeMCU v2 oraz

MPU6050, rozmieszczone na niej otwory umożliwiły zamontowanie jej do ramy za pomocą

śrub. Jest zorientowana modułem MPU6050 do przodu multikoptera. Ze względu na

zmianę orientacji modułu MPU6050 względem płytki stykowej należało zamienić jego osie

w kodzie kontrolera lotu.

Ostatnim krokiem było wykonanie obwodu elektrycznego źródła zasilania. W tym

celu wykorzystano przewody o wydajności prądowej do 54,5A dla połączenia od

akumulatora do rozgałęzienia na poszczególne regulatory ESC oraz o wydajności do 18A od

rozgałęzienia do regulatorów ESC. W celu połączenia układu ze źródłem zasilania

zastosowano wtyczkę XT60 oraz przycisk bistabilny, połączenie do przycisku oraz

regulatorów ESC zostało doprowadzone za pomocą konektorów.

Rys. 2.6. Połączony układ sterowania

### 2.2. Wykonanie oprogramowania sterującego

Wykonanie oprogramowania sterującego odbyło się za pomocą środowiska Arduino

IDE 1.8.18 skonfigurowanego w sposób umożliwiający mu komunikację z płytką NodeMCU

v2. Oprogramowanie sterujące ma za zadanie odczytywać komendy przesyłane przez

interfejs sterujący oraz informacje z czujników położenia, a następnie tak zmieniać sygnały

sterujące prędkością obrotową poszczególnych zespołów napędowych aby otrzymać

pożądany efekt podczas lotu.

Podczas początkowej fazy tworzenia oprogramowania dużym ułatwieniem było

wykonanie kompaktowego układu elektrycznego na płytce stykowej. Do nawiązania

komunikacji między aplikacją na telefonie (interfejsem sterującym) a płytką zastosowano

biblioteki i funkcje udostępnione przez autora aplikacji. Aby sterowanie było możliwe

zostały napisane funkcje: pitchFront(), pitchBack(), rollLeft(), rollRight(), yawRight(),

yawLeft() które odpowiadają za przechylenia statku powietrznego względem osi x (prawo, lewo) i y (przód, tył) a także obrót wokół osi z (śmigieł). Zmienna throttle została stworzona

w celu przechowywania stopnia otwarcia przepustnicy sterowanego za pomocą suwaka w

interfejsie. W celu połączenia funkcji ruchu z komendami zastosowano instrukcje

warunkowe. Fragment kodu odpowiedzialny za odczytywanie przechylenia został napisany

w oparciu o artykuł poświęcony modułowi MPU6050 [25]. Wartości przechyleń zostały

zsumowana algebraicznie w sposób zależny od lokalizacji diody (zespołu napędowego) z

poziomem otwarcia przepustnicy. W ten sposób podczas przechylenia układu dioda

znajdująca się poniżej środka ciężkości otrzymywał większą, a ta powyżej mniejszą moc, co

ma symulować dostosowywanie prędkości obrotowych silników do przechylenia

multikoptera. Aby móc regulować oddziaływanie wartości kąta przechylenia układu na

wartość sygnału sterującego diodami wykonano regulatory PD dla osi x oraz y [14]. Na tym

etapie możliwe było sterowanie jasnością diod za pomocą aplikacji oraz kąta przechylenia

układu za pośrednictwem sygnałów PWM. Wykorzystano także funkcje Serial.print() w celu

wyświetlenia w monitorze portu szeregowego informacji na temat najważniejszych

zmiennych.

Podczas zmiany diod na docelowe regulatory ESC wraz z silnikami układ przestał

reagować. Konieczne było zastosowanie biblioteki „Servo.h” oraz dodanie do kodu

fragmentu odpowiedzialnego za ustawienie regulatorów ESC czyli: zdefiniowanie portu

oraz minimalnej i maksymalnej szerokości impulsu sygnału PWM. Należało także zamienić

rozdzielczość sygnału PWM z zakresu 0 - 255 na 0 - 180 do czego wykorzystano funkcję

map() [3]. Wymagana okazała się być także zamiana portów z D7 i D8 na D0 i D3, ponieważ

te pierwsze nie chciały współpracować z regulatorami ESC. W następnym etapie okazało

się, że zmienna throttle najpierw musi zostać wykorzystana do obliczeń w swojej

pierwotnej postaci (zakres 0 - 255) a dopiero w następnej kolejności może zostać

zamieniona na zakres 0 – 180, ponieważ odwrotne działanie prowadziło do „zawieszenia

się algorytmu”. W tym celu zmienianie rozdzielczości sygnału PWM z 0 - 255 na 0 - 180

zostało przeprowadzone osobno dla wszystkich sygnałów sterujących silnikami.

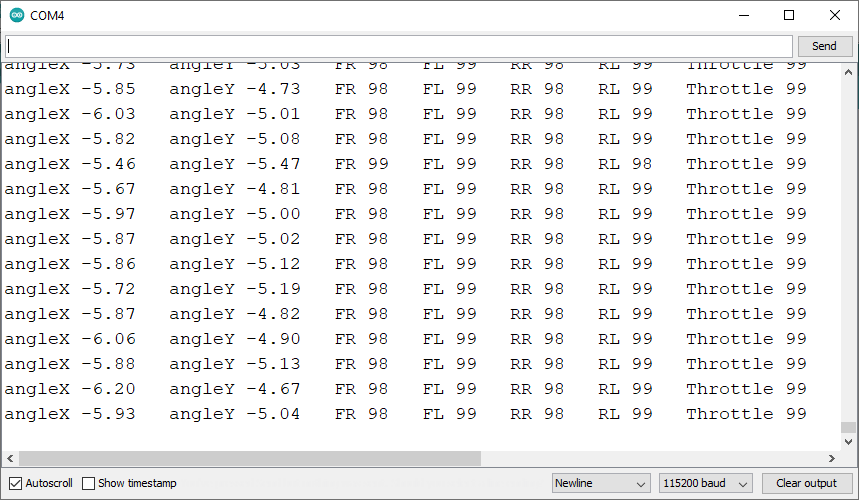
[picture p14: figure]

Rys. 2.7. Monitor portu szeregowego

Do zmiennych umożliwiających zmianę parametrów lotu należą: XKp, XKd, YKp, YKd

są to nastawy regulatora PD odpowiadające za czułość stabilizacji lotu poprzez odczyty z

czujników położenia. Kolejne zmienne to: Move1 – współczynnik odpowiadający za

zwiększenie ciągu podczas funkcji ruchu, Move2 – współczynnik zmniejszający ciąg podczas

funkcji ruchu, są odpowiedzialne za to jak bardzo statek powietrzny ma przechylić się w

daną stronę podczas ruchu np. podczas lotu do przodu, decyduje to o jego prędkości i

stabilności.

Ostateczna wersja kodu sterującego multikopterem:

// DEFINIOWANIE PINÓW STERUJĄCYCH ŚILNIKAMI

#define FR_PIN D5 // D5 Przedni prawy OBRÓT W LEWO

#define FL_PIN D6 // D6 Przedni lewy OBRÓT W PRAWO

#define RR_PIN D0 // D0 Tylny prawy OBRÓT W PRAWO

#define RL_PIN D3 // D3 Tylny lewy OBRÓT W LEWO

// DOŁĄCZENIE WYMAGANYCH BIBLIOTEK

#include <Wire.h>

#include <ESP8266WiFi.h>

#include <WiFiClient.h>

#include <ESP8266WebServer.h>

#include<Servo.h>

// DEFINIOWANIE PINÓW STERUJĄCYCH SILNIKAMI DLA BIBLIOTEKI SERVO

Servo FR, FL, RR, RL;

// KOMUNIKACJA WiFi

String command;

const char* ssid = "DRON_ESP32"; // nazwa sieci

ESP8266WebServer server(80);

// ŻYROSKOP / AKCELEROMETR MPU6050

float angleX; // Kąt pochylenia względem osi X

float angleY; // Kąt pochylenia względem osi Y

const int MPU_addr = 0x68;

int16_t AcX, AcY, AcZ, Tmp, GyX, GyY, GyZ;

int minVal = 265;

int maxVal = 402;

// REGULATOR PD

float XKp = 0.04, XKd = 0.5; //Nastawy regulatora osi X

float YKp = 0.04, YKd = 0.5; //Nastawy regulatora osi Y

int setTime = 20; // (dt Czas po jakim pobiera się próbkę) Czas po którym zostanie ponownie przeliczona wartość wyjścia

float XPout, XDout; //Przechowują wyniki obliczeń członów regulatora osi X

float YPout, YDout; //Przechowują wyniki obliczeń członów regulatora osi Y

float Xout; //Wyjście regulatora osi X

float Yout; //Wyjście regulatora osi Y

float now, lastTime, timeChange; //Zmienne konieczne do ustalenia czasu ponownego przeliczenia wyjścia w regulatorze PD

float Xinput; //Sygnał z Żyroskopu / akcelerometru dla osi X (kąt)

float Yinput; //Sygnał z Żyroskopu / akcelerometru dla osi Y (kąt)

float Xerror, XlastError; //Błąd w obecnej i poprzedniej chwili czasu dla osi X

float Yerror, YlastError; //Błąd w obecnej i poprzedniej chwili czasu dla osi Y

float setPoint = 0; //Docelowy kąt dla osi X i Y

float XDerror; //Suma błędów dla części różniczkującej dla osi X

float YDerror; //Suma błędów dla części różniczkującej dla osi Y

// FUNKCJE STEROWANIA

float Move1 = 1.18; // Współczynnik dla zwiększenia ciągu

float Move2 = 1.18; // Współczynnik dla zmniejszenia ciągu

int throttle, throttle180, FRxy, FLxy, RRxy, RLxy; // Zmienne dla obliczania sygnału sterującego silnikami

void pitchFront(){ // Przechylenie do przodu

FR.write(throttle180 / Move2);

FL.write(throttle180 / Move2);

RR.write(throttle180 * Move1);

RL.write(throttle180 * Move1);

}

void pitchBack(){ // Przechylenie do tyłu

FR.write(throttle180 * Move1);

FL.write(throttle180 * Move1);

RR.write(throttle180 / Move2);

RL.write(throttle180 / Move2);

}

void rollLeft(){ // Przechylenie w lewo

FR.write(throttle180 * Move1);

FL.write(throttle180 / Move2);

RR.write(throttle180 * Move1);

RL.write(throttle180 / Move2);

}

void rollRight(){ // Przechylenie w prawo

FR.write(throttle180 / Move2);

FL.write(throttle180 * Move1);

RR.write(throttle180 / Move2);

RL.write(throttle180 * Move1);

}

void yawRight(){ // Obrót w prawo

FR.write(throttle180 / Move2);

FL.write(throttle180 * Move1);

RR.write(throttle180 * Move1);

RL.write(throttle180 / Move2);

}

void yawLeft(){ // Obrót w lewo

FR.write(throttle180 * Move1);

FL.write(throttle180 / Move2);

RR.write(throttle180 / Move2);

RL.write(throttle180 * Move1);

}

void setup() {
// NAWIĄZANIE KOMUNIKACJI PORTU SZEREGOWEGO NA PRĘDKŚCI 115200

Serial.begin(115200);

// KOMUNIKACJA WiFi

WiFi.mode(WIFI_AP);

WiFi.softAP(ssid);

IPAddress myIP = WiFi.softAPIP();

Serial.print("AP IP address: ");

Serial.println(myIP);

// Starting WEB-server

server.on ( "/", HTTP_handleRoot );

server.onNotFound ( HTTP_handleRoot );

server.begin();

// NAWIĄZANIE KOMUNIKACJI Z ŻYROSKOPEM / AKCELEROMETREM MPU6050

Wire.begin();

Wire.beginTransmission(MPU_addr);

Wire.write(0x6B);

Wire.write(0);

Wire.endTransmission(true);

// USTAWIENIE REGULATORÓW ESC

FR.attach(FR_PIN, 1000, 2000); // Numer portu, minimalna szerokość impulsu (ms), maksymalna szerokość impulsu (ms)

FL.attach(FL_PIN, 1000, 2000);

RR.attach(RR_PIN, 1000, 2000);

RL.attach(RL_PIN, 1000, 2000);

FR.write(0); // Wyłączenie silników

FL.write(0);

RR.write(0);

RL.write(0);

delay(2000);

}

void loop() {

//POŁOŻENIE ŻYROSKOP / AKCELEROMETR MPU6050

// angleX + przechylenie w prawo

// angleX - przechylenie w lewo

// angleY + przechylenie do tyłu

// angleY - przechylenie do przodu

Wire.beginTransmission(MPU_addr);

Wire.write(0x3B);

Wire.endTransmission(false);

Wire.requestFrom(MPU_addr,14,true);

AcX = Wire.read()<<8|Wire.read();

AcY = Wire.read()<<8|Wire.read();

AcZ = Wire.read()<<8|Wire.read();

int xAng = map(AcX,minVal,maxVal,-90,90);

int yAng = map(AcY,minVal,maxVal,90,-90);

int zAng = map(AcZ,minVal,maxVal,-90,90);

angleX = RAD_TO_DEG * (atan2(-yAng, -zAng)+PI) - 180;

angleY = RAD_TO_DEG * (atan2(-xAng, -zAng)+PI) - 180;

// REGULATOR PD

Xinput = angleX; // Przypisanie do wejścia regulatora wartości kąt przechylenia

Yinput = angleY;

// OBLICZENIE CZASU DO PONOWNEJ REGULACJI

now = millis(); // Czas jaki upłynął od włączenia urządzenia

timeChange = now - lastTime; // Różnica między aktualnym czasem a zapamiętanym

if (timeChange >= setTime) // Jeśli zmiana czasu >= od ustawionego czasu dla timera to ustawiony czas minął

{
// OBLICZENIE WYJŚCIA REGULATORA DLA OSI X

Xerror = setPoint - Xinput; // Część proporcjonalna (wymagany kąt - aktualny kąt)

XDerror = (Xerror - XlastError) / timeChange; // Część różniczkująca

XPout = XKp * Xerror; // Przemnożenie części proporcjonalnej przez nastawę

XDout = XKd * XDerror; // Przemnożenie części różniczkującej przez nastawę

Xout = XPout + XDout; // Obliczenie wartości wyjścia regulatora

XlastError = Xerror; // Ustawienie nowej wartości dla poprzedniego błędu

// OBLICZENIE WYJŚCIA REGULATORA DLA OSI Y

Yerror = setPoint - Yinput;

YDerror = (Yerror - YlastError) / timeChange;

YPout = YKp * Yerror;

YDout = YKd * YDerror;

Yout = YPout + YDout;

YlastError = Yerror;

lastTime = now; // Ustawienie nowej wartości dla zapamiętanego czasu

}

// KOMUNIKACJA WiFi

server.handleClient();

// KOMENDY STEROWANIA (Telefon pionowo)

//strzałka w górę F

//strzałka w dół B

//strzałka w lewo L

//strzałka w prawo R

//strzałka w góra prawo I

//strzałka w góra lewo G

//strzałka w dół prawo J

//strzałka w dół lewo H

//przycisk na środku S

// OPÓŹNIENIE PRZED ZMIANĄ OTWARCIA PRZEPUSTNICY NIWELUJĄCE ZAKŁÓCENIA

int lastTime2;

int timeChange2 = now - lastTime2;

int delay1 = 50; // Czas trwania opóźnienia

// PRZYPISANIE FUNKCJI RUCHU DO OTRZYMANEJ KOMENDY

command = server.arg("State"); // Funkcja odczytująca komendę

if (command == "R") pitchFront();

else if (command == "L") pitchBack();

else if (command == "F") rollLeft();

else if (command == "B") rollRight();

else if (command == "I") yawRight();

else if (command == "J") yawLeft();

//else if (command == "0") throttle = 0; // Nie korzystać z położenia 0

else if (command == "1" && timeChange2 >= delay1) throttle = 0;

else if (command == "2" && timeChange2 >= delay1) throttle = 50;

else if (command == "3" && timeChange2 >= delay1) throttle = 70;

else if (command == "4" && timeChange2 >= delay1) throttle = 90;

else if (command == "5" && timeChange2 >= delay1) throttle = 100;

else if (command == "6" && timeChange2 >= delay1) throttle = 120;

else if (command == "7" && timeChange2 >= delay1) throttle = 130;

else if (command == "8" && timeChange2 >= delay1) throttle = 140; // MAX 200

//else if (command == "9") throttle = 200; // Nie korzystać z położenia 9

// ZMIANA ROZDZIELCZOŚCI SYGNAŁU PWM Z 255 NA 180 DLA PRZEPUSTNICY

throttle180 = map(throttle, 0, 255, 0, 180);

// OBLICZENIE SYGNAŁU PWM DLA POSZCZEGÓLNEGO SILNIKA Z UWZGLĘDNIENIEM PRZEPUSTNICY I POCHYLENIA

FRxy = throttle + Yout - Xout;

FLxy = throttle + Yout + Xout;

RRxy = throttle - Yout - Xout;

RLxy = throttle - Yout + Xout;

// ZABEZPIECZENIE PRZED PRZEKROCZENIEM ZAKRESU PWM

if (FRxy > 255) FRxy = 255;

if (FLxy > 255) FLxy = 255;

if (RRxy > 255) RRxy = 255;

if (RLxy > 255) RLxy = 255;

if (FRxy < 0) FRxy = 0;

if (FLxy < 0) FLxy = 0;

if (RRxy < 0) RRxy = 0;

if (RLxy < 0) RLxy = 0;

// ZMIANA ROZDZIELCZOŚCI SYGNAŁU PWM Z 255 NA 180 DLA STEROWANIA SILNIKAMI

FRxy = map(FRxy, 0, 255, 0, 180);

FLxy = map(FLxy, 0, 255, 0, 180);

RLxy = map(RLxy, 0, 255, 0, 180);

RRxy = map(RRxy, 0, 255, 0, 180);

// USTAWIENIE PRĘDKOŚCI SILNIKÓW NA OBLICZONĄ

FR.write(FRxy);

FL.write(FLxy);

RR.write(RRxy);

RL.write(RLxy);

//WYŚWIETLANIE PARAMETRÓW NA MONITORZE PORTU SZEREGOWEGO

Serial.print("angleX "); // Przechylenie lewo+, prawo- (stopnie)

Serial.print(angleX);

Serial.print(" ");

Serial.print("angleY "); // Przechylenie tył+, przód- (stopnie)

Serial.print(angleY);

Serial.print(" ");

Serial.print("FR "); // Silnik przód prawy, sygnał PWM (180)

Serial.print(FRxy);

Serial.print(" ");

Serial.print("FL "); // Silnik przód lewy, sygnał PWM (180)

Serial.print(FLxy);

Serial.print(" ");

Serial.print("RR "); // Silnik tył prawy, sygnał PWM (180)

Serial.print(RRxy);

Serial.print(" ");

Serial.print("RL "); // Silnik tył lewy, sygnał PWM (180)

Serial.print(RLxy);

Serial.print(" ");

Serial.print("Throttle "); // Przepustnica PWM (180)

Serial.print(throttle180);

Serial.print("\n");

lastTime2 = now; // Zapamiętany czas dla redukcji zakłóceń

}

// KOMUNIKACJA WiFi

void HTTP_handleRoot(void) {

if( server.hasArg("State") ){

Serial.println(server.arg("State"));

}

server.send ( 200, "text/html", "" );

delay(1);

}

## 3. UKŁAD MECHANICZNY

Układ mechaniczny stanowi rama wraz z zespołami napędowymi. Są to elementy na

które działają największe siły i od ich właściwości fizycznych zależą możliwości lotu.

Parametry ramy muszą być odpowiednio dopasowane do parametrów zespołu

napędowego.

### 3.1. Projektowanie ramy

Rama jest podstawowym elementem każdego wielowirnikowca ma za zadanie

zapewnić optymalne rozmieszczenie podzespołów, sztywność podczas lotu i ochronę

podzespołów podczas ewentualnych kolizji. Podstawowymi parametrami podczas

dobierania ramy jest jej klasa, przewidziana ilość zespołów napędowych, a także rozstaw

otworów przeznaczonych dla ich montażu. Klasa stanowi o wielkości ramy, jest to odległość

między dwoma przeciwległymi zespołami napędowymi mierzona po przekątnej podawana

w milimetrach. Wybór ramy o danej klasie zależy od rozmiaru śmigieł. Ważne, aby odległość

między zespołami napędowymi była na tyle duża, by śmigła nie kolidowały ze sobą.

Tab. 3.1. Przewidziana klasa ramy dla danego rozmiaru śmigieł [opracowanie własne]

Klasa ramy | Rozmiar śmigieł
180 | Do 4"
250 | 5"-6"
330 | 6"-8"
450 | 10"-12"

Rys. 3.1. Przykładowa rama klasy 250 [26]

Materiały z jakich wykonuje się ramy dla multikopterów to między innymi: drewno,

tworzywa sztuczne, aluminium, włókno węglowe. Włókno węglowe jest wytrzymałe,

bardzo lekkie i sztywne. Jego wady to: wysoka cena, oraz podczas uszkodzeń może zacząć

się kruszyć. Do naprawy włókna węglowego używa się żywicy epoksydowej lub kleju

cyjanoakrylowego, w tym materiale nie można wiercić ponieważ łatwo pęka. Aluminium z

kolei posiada zalety włókna węglowego, jest nieco cięższe i trochę mniej sztywne. Ma przewagę nad włóknem węglowym ze względu na niższą cenę, oraz możliwość obróbki, co

upraszcza naprawę uszkodzonej ramy [15].

Do przeprowadzenia pełnych testów napisanego kodu oraz wykonanego układu

elektrycznego konieczne było zaprojektowanie oraz wykonanie ramy prototypowej z łatwo

dostępnego materiału. Projekt został wykonany w programie Autodesk Inventor 2023. Do

jego wykonania zastosowano konstrukcje blachowe które następnie zostały połączone w

zespół. Rama została zaprojektowana w standardzie klasy 450, oraz tak aby możliwe było

zamontowanie silników o rozstawie otworów 33 x 33mm, a także płytki uniwersalnej 64 x

44mm.

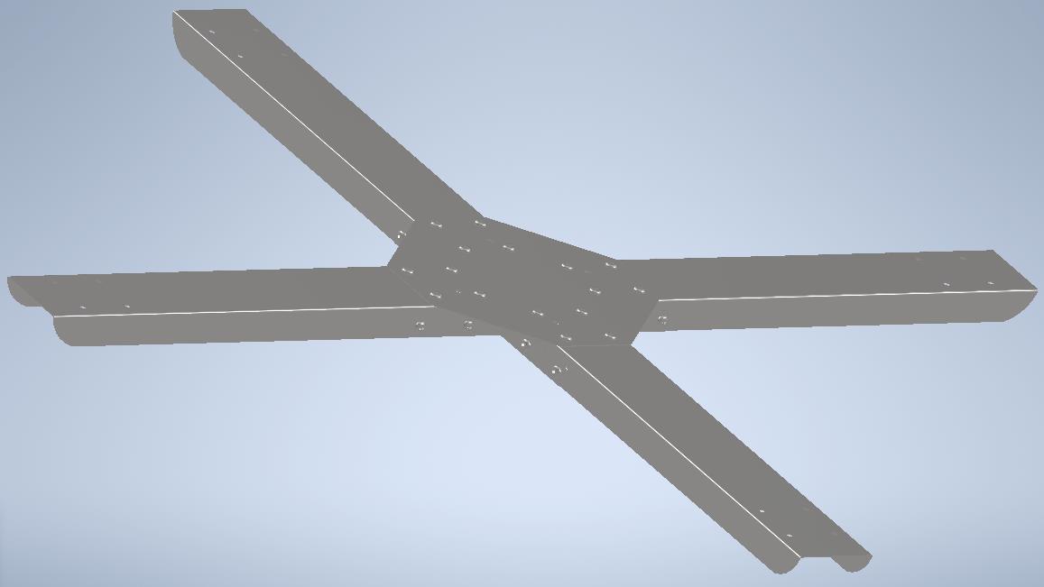
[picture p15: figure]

Rys. 3.2. Zaprojektowana rama prototypowa (zespół)

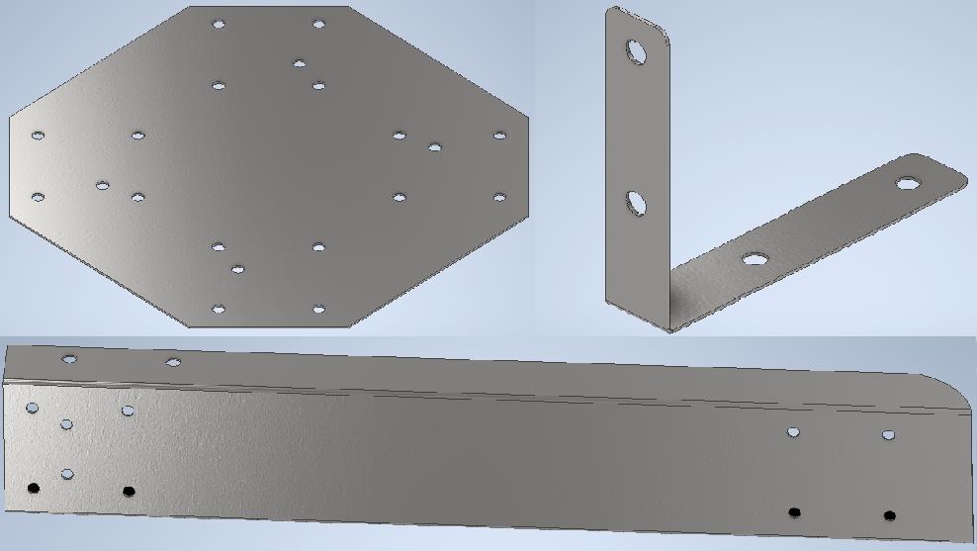
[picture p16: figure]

Rys. 3.3. Zaprojektowane części ramy prototypowej

Przeprowadzona analiza wytrzymałościowa ramy prototypowej wykazała, że

konstrukcja wytrzymuje maksymalnie siłę 180N podzieloną na 4 ramiona. Wskazuje na to wartość współczynnika wytrzymałości która jest większa od 1. Środek konstrukcji został

unieruchomiony, a siła została przyłożona w miejscach montażowych zespoły napędowe.

Siła 180N oznacza, że konstrukcja wytrzyma nacisk około 18 kg podzielony na 4 ramiona.

Siła ta spowodowała, że końce ramion przemieszczają się maksymalnie o około 0,89mm w

kierunku działania siły. Cała konstrukcja ma ważyć około 0,330 kg i zostać wykonana z

blachy stalowej ocynkowanej o grubości 0,5mm.

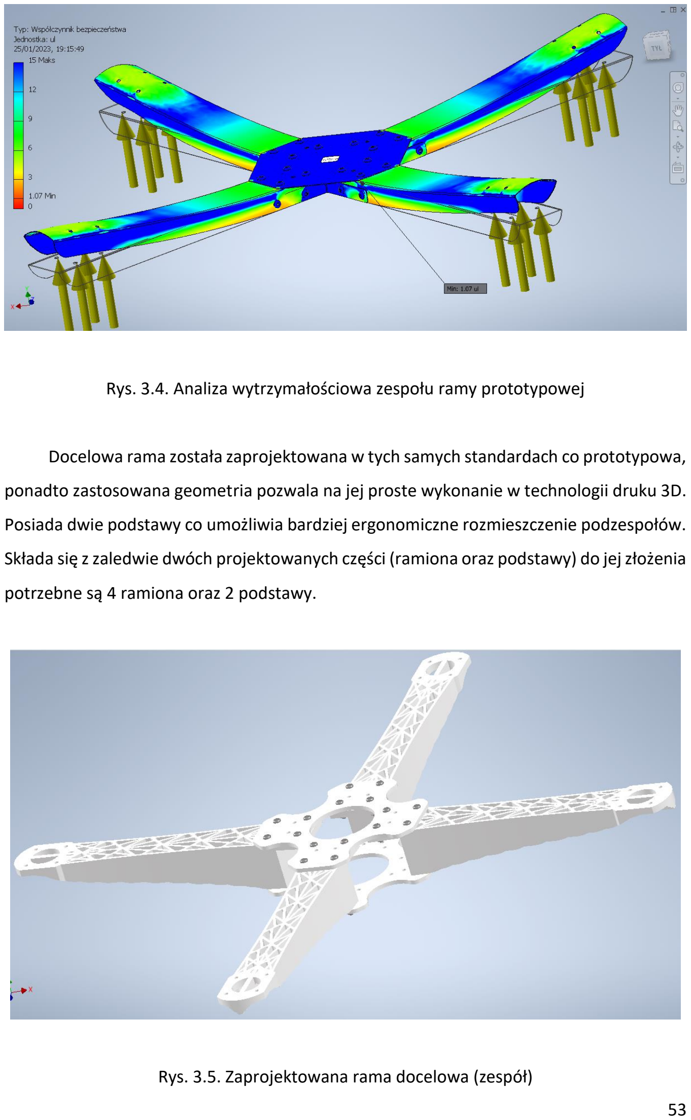
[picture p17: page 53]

Rys. 3.4. Analiza wytrzymałościowa zespołu ramy prototypowej

Docelowa rama została zaprojektowana w tych samych standardach co prototypowa,

ponadto zastosowana geometria pozwala na jej proste wykonanie w technologii druku 3D.

Posiada dwie podstawy co umożliwia bardziej ergonomiczne rozmieszczenie podzespołów.

Składa się z zaledwie dwóch projektowanych części (ramiona oraz podstawy) do jej złożenia

potrzebne są 4 ramiona oraz 2 podstawy.

Rys. 3.5. Zaprojektowana rama docelowa (zespół)

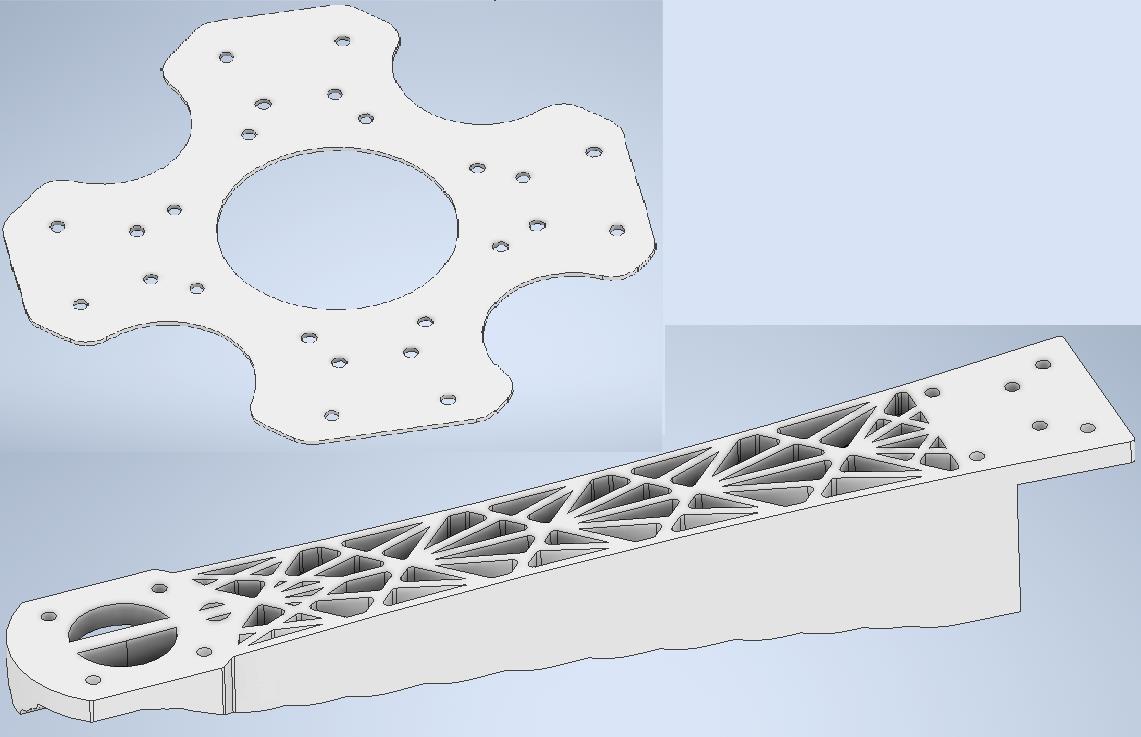
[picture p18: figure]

Rys. 3.6. Zaprojektowane części ramy docelowej

Przeprowadzona analiza wytrzymałościowa docelowej ramy wykazała, że konstrukcja

ta również wytrzymuje siłę do 180N tak jak wariant z blachy, a przy tym jest od niego lżejsza.

Dla tej symulacji maksymalne przemieszczenie końców ramion wynosi 3,9mm. Dodatkowo

przeprowadzono symulację dla siły skręcającej jedno ramię. Wypadkowa obydwu sił

skręcających wynosiła 60N. Rama była na granicy pęknięcia ponieważ współczynnik

wytrzymałości wynosił 1,01. Siła ta spowodowała, że koniec ramiona przemieszcza się

maksymalnie o około 3,5mm w kierunku działania sił. Wyniki projektowe są zadowalające,

ponieważ wytrzymałość ramy jest dość duża, a masa profesjonalnej ramy tej klasy wynosi

0,282kg. Zaprojektowana konstrukcja ramy ma ważyć około 0,304 kg i zostać wykonana z

ABS w technologii druku 3D.

Rys. 3.7. Analiza wytrzymałościowa zespołu ramy docelowej dla siły skierowanej do góry

Rys. 3.8. Analiza wytrzymałościowa zespołu ramy docelowej dla siły skręcającej ramie

### 3.2. Wykonanie ramy

Wykonanie części ramy prototypowej odbyło się poprzez odpowiednie wycięcie i

wygięcie stalowej ocynkowanej blachy o grubości 0,5mm. Części zostały połączone za

pomocą zestawu śrub M3x6, podkładek M3 oraz nakrętek M3.

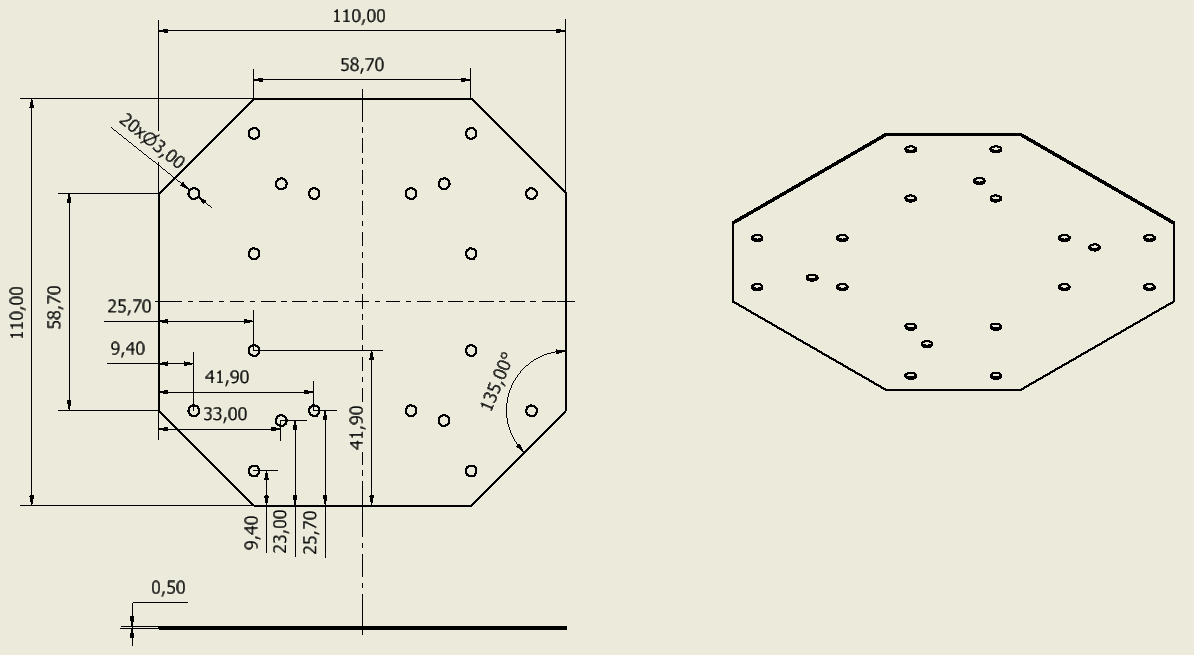
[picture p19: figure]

Rys. 3.9. Schemat wykonania części środkowej dla ramy prototypowej

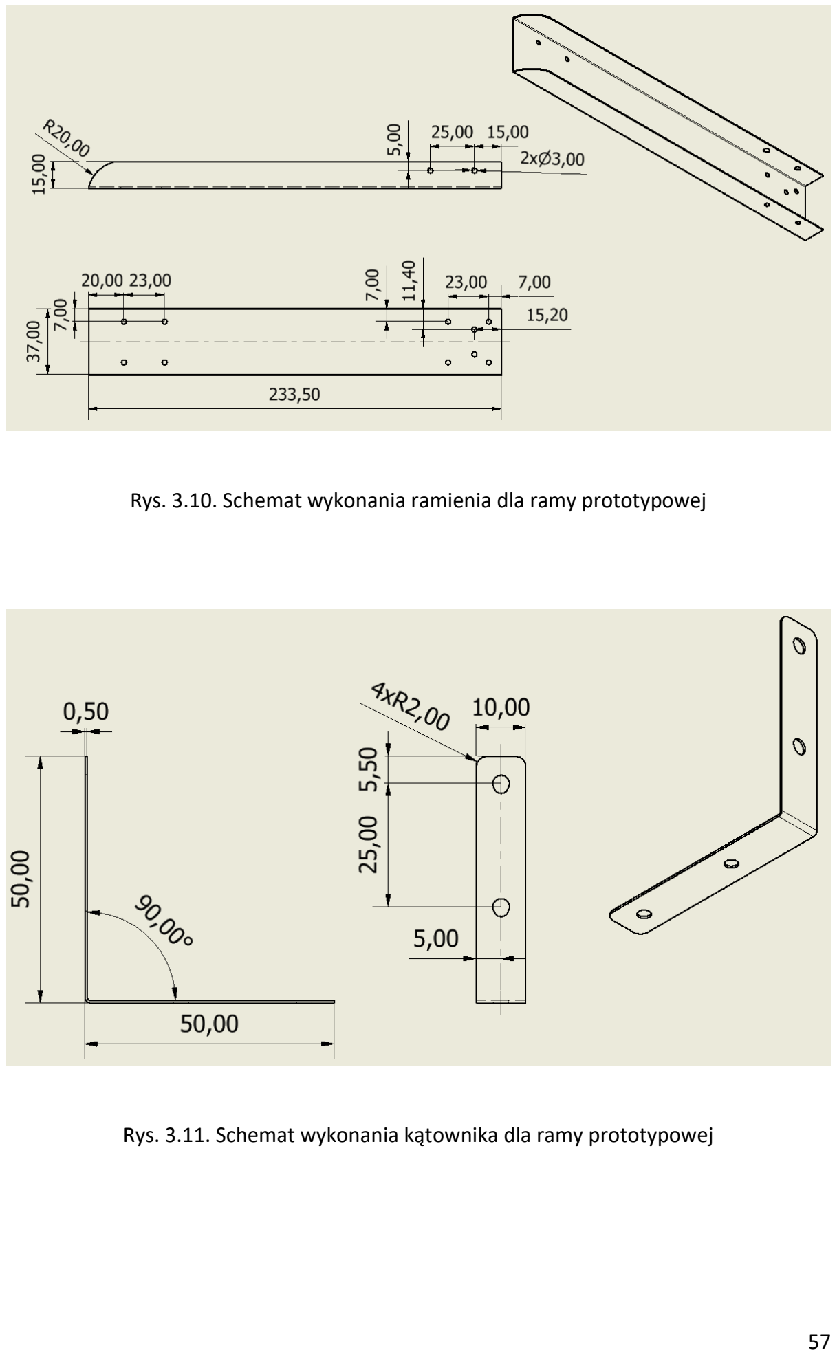
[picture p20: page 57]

Rys. 3.10. Schemat wykonania ramienia dla ramy prototypowej

Rys. 3.11. Schemat wykonania kątownika dla ramy prototypowej

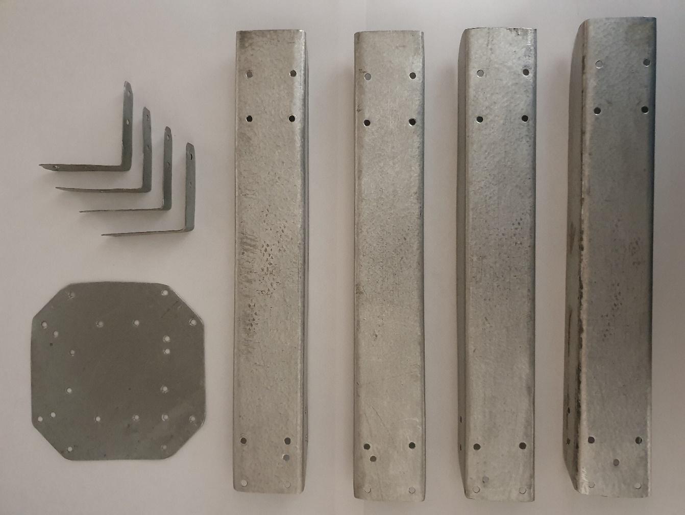
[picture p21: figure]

Rys. 3.12. Wykonane części ramy prototypowej.

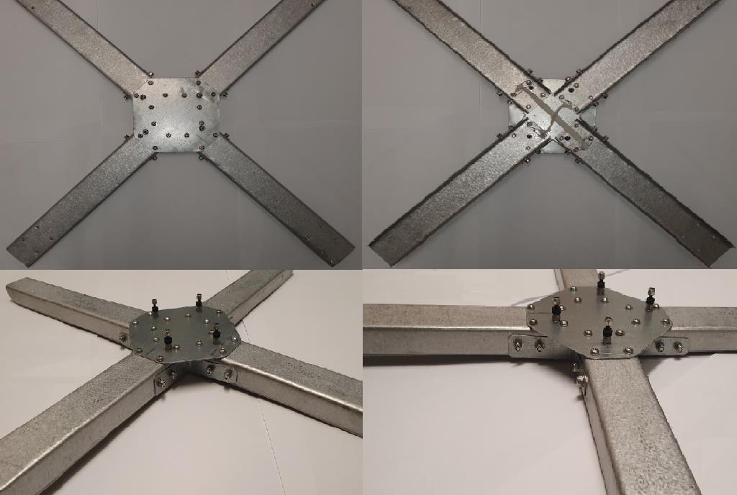
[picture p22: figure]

Rys. 3.13. Zmontowana rama prototypowa.

Rama o docelowej konstrukcji miała zostać wykonana z materiału ABS w technologii

druku 3D, jednak przez awarię drukarki nie zostało to zrealizowane. Części zaprojektowane

w programie Autodesk Inventor 2023 zostały zapisane jako format .stl. Do

przekonwertowania plików .stl na g-code zastosowano oprogramowanie ideaMaker,

można je pobrać za darmo ze strony producenta: https://www.raise3d.com/ideamaker/

[dostęp: 31.01.2023 r.].

Drukowanie miało charakteryzować się z następującymi parametrami:

- średnica dyszy: 0,6mm
- wysokość warstwy: 0,4mm
- szerokość warstwy: 1,2mm
- gęstość wypełnienia 30%

Czas drukowania jednego ramiona wynosi około 1 godziny i 46 minut, wykorzystane

zostanie około 57,4g filamentu. Czas drukowania jednej podstawy wynosi około 31 minut,

wykorzystane zostanie około 22,3g filamentu. Reasumując dla całego zespołu ramy

wykorzystane zostanie około 274,2g filamentu. Koszt wydruku całego zespołu biorąc pod

uwagę jedynie ceny filamentu ABS z dnia 26.01.2023 wyniósłby około 22 złote.

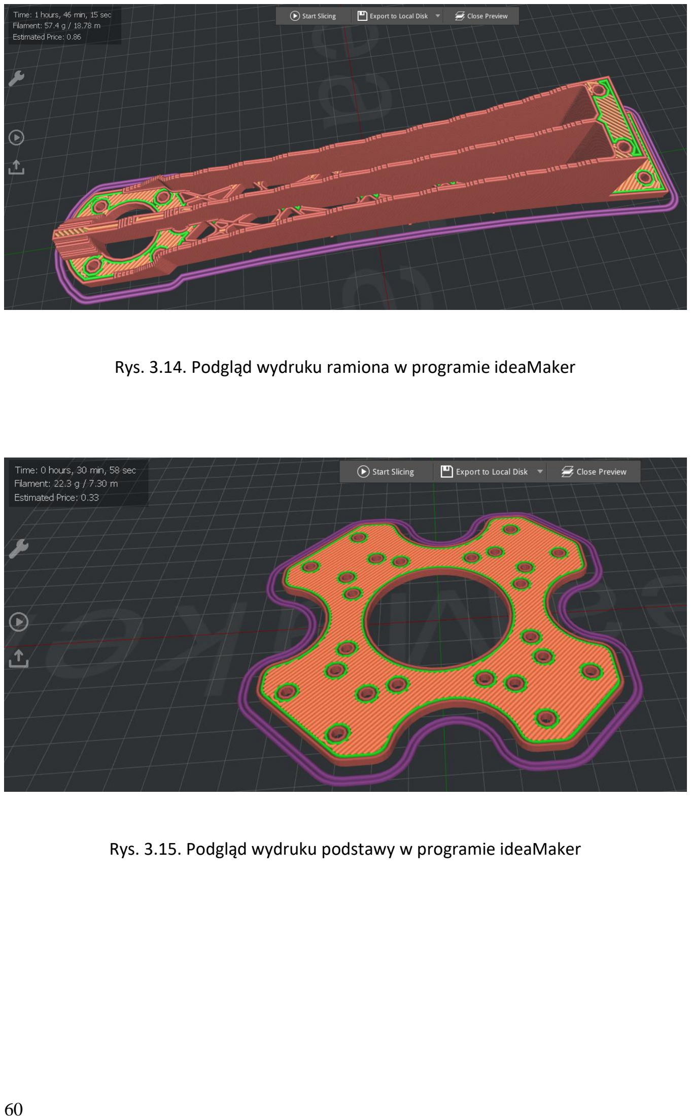
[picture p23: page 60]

Rys. 3.14. Podgląd wydruku ramiona w programie ideaMaker

Rys. 3.15. Podgląd wydruku podstawy w programie ideaMaker

### 3.3. Rozmieszczenie elementów na ramie

Rozmieszczenie elementów na ramie prototypowej odbyło się za pomocą zespołów

śrub, podkładek, nakrętek w standardzie M3, oraz opasek zaciskowych. Na górnej części

ramy zostały rozmieszczone: płytka PCB, regulatory ESC, oraz zespoły napędowe, a także

łączące je przewody . Płytka PCB jak i zespoły napędowe zostały zamocowane za pomocą

połączenia śrubowego w oparciu o przeznaczone do tego otwory. Regulatory ESC wraz z

wyprowadzonymi z nich przewodami znajdują się pomiędzy płytką PCB a zespołami

napędowymi i są zamocowane za pomocą opasek zaciskowych. Za pomocą kolejności

podłączenia przewodów między regulatorami ESC, a zespołami napędowymi decyduje się

o kierunku obrotu silników, dla tego modelu ustalone są następujące kierunki obrotów:

- przedni prawy silnik - obrót w lewo
- przedni lewy silnik - obrót w prawo
- tylny prawy silnik - obrót w prawo
- tylny lewy silnik - obrót w lewo

Gdzie kierunek przedni jest określany przez umiejscowienie modułu MPU6050 na płytce

PCB.

Od dolnej strony ramy znajdują się: źródło zasilania z wyprowadzonymi przewodami

oraz włącznik. Akumulator został zamocowany za pomocą gumy krawieckiej w środkowej

części konstrukcji. Włącznik jak i przewody zostały zamocowane za pomocą opasek

zaciskowych. Przewody zostały poprowadzone przez lukę znajdującą się po między

kątownikami a podstawą ramy.

Rys. 3.16. Rozmieszczenie elementów na ramie

### 3.4. Przeprowadzenie testów

Ponieważ docelowa konstrukcja ramy nie została wykonana testy zostały

przeprowadzone dla konstrukcji wykonanej na ramię prototypowej. Pierwszą rzeczą jaką

zaobserwowano jeszcze podczas testu na diodach były duże zakłócenia podczas sterowania

poziomem otwarcia przepustnicy występujące zwykle na poziomie minimum a rzadziej na

maksimum, objawiało się to nagłym zwiększeniem lub zmniejszeniem mocy co było

kłopotliwe podczas testów z już zamontowanymi śmigłami. Zasięg na świeżym powietrzu

wynosi około 20 metrów, co dla przeprowadzanych testów było wystarczające. Cały model ważył około 1kg co dawało mu stosunek ciągu do masy na poziomie 3:1. Taka wartość

powinna pozwolić na efektywne latanie, w praktyce jednak okazało się, że przy większych

obrotach silników całość wpadała w duże wibracje co powodowało turbulencje, a następnie

spadanie kwadrokoptera. Sterowanie za pomocą interfejsu powoduje, że model zamierza

poruszyć się we wskazanym mu kierunku, jednak efekt opisany powyżej to uniemożliwia.

Podczas ręcznego przechylenia statku powietrznego odczuwa się efekt regulacji mocy

silników mający na celu jego powrót do pozycji poziomej. Zmiany nastaw regulatora PD jak

i parametrów ruchu w dużym stopniu wpływają na zachowanie modelu. Reasumując

wykonany kwadrokopter jest w stanie się unieść, jednak po kilku sekundach wpada w

turbulencje i spada.

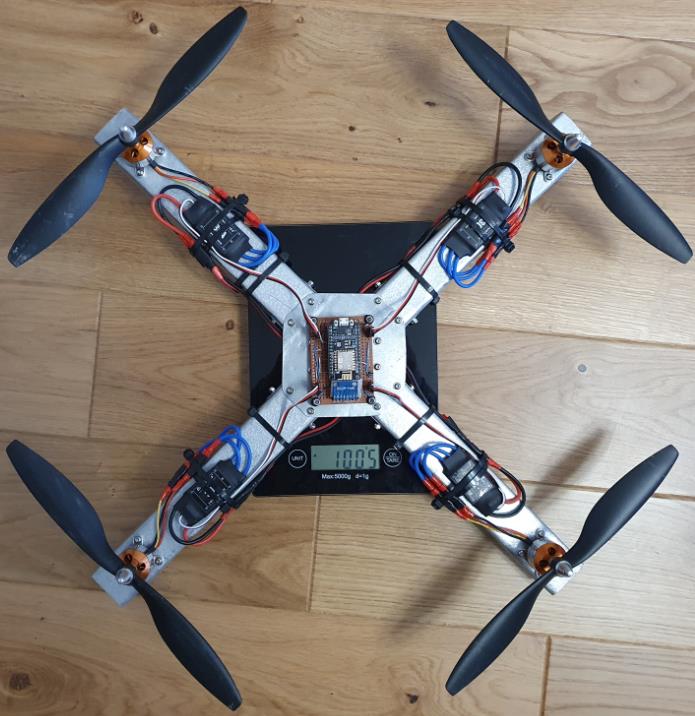
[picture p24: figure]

Rys. 3.17. Pomiar masy wykonanego kawdrokoptera

## PODSUMOWANIE

Podczas wykonywania pracy inżynierskiej udało się zaprojektować oraz wykonać

kawdrokopter. Przeprowadzone na nim testy wykazały zakłócenia w komunikacji między

smartfonem a kontrolerem lotu. Przyczyną tego może być błąd w aplikacji sterującej lub

zakłócenia sieci WiFi. Niewielki zasięg sygnału może zostać zwiększony przez zastosowanie

anteny zewnętrznej podłączonej do modułu ESP32. Poprawę z pewnością przyniosłoby

zastosowanie lepszej aplikacji sterującej lub w ostateczności zmiana metody komunikacji

na radiową. Przyczyną zaobserwowanych wibracji okazała się być mało sztywna rama

prototypowa, zastosowanie docelowej konstrukcji wykonanej w technologii druku 3D z

pewnością zniwelowałoby to zjawisko. Działanie systemu sterowania było prawidłowe, nie

wliczając zakłóceń kwadrokopter reagował poprawnie na wszystkie komendy bez

widocznego opóźnienia. Urządzenie odczytujące orientację modelu działało bardzo szybko

i precyzyjnie, największą trudność stanowiło odpowiednie dobranie nastaw regulatora PD

odpowiedzialnych za stabilizację koptera. Całkowita masa obiektu wynosiła 1005g,

zastosowanie docelowej ramy pozwoliło ją nieco zmniejszyć. Stosunek maksymalnego

ciągu do masy na poziomie około 3:1 jest dobrym wynikiem. Po wprowadzeniu powyższych

zmian i osiągnięciu poprawnego efektu lotu w przyszłości korzystne będzie zastosowanie

akumulatora o większej pojemności oraz kamery.

## BIBLIOGRAFIA

Książki i artykuły naukowe:

[1] Andrzej Jaskulski: Autodesk Inventor Professional 2021 PL / 2021+ / Fusion 360.

Metodyka projektowania. Helion, Gliwice, 2020.

[2] Damian Szymański: ESP8266 - co warto wiedzieć?. FORBOT, Poznań, 2020.
[3] Dejan: Arduino Brushless Motor Control Tutorial ESC BLDC. How To Mechatronics,

San Francisco, 2019.

[4] EBMiA: Silnik bezszczotkowy BLDC – co to jest, jak działa, zastosowanie, zalety.

Wiedza EBIMA, Augustów, 2021.

[5] F3M: Geneza powstania dronów. F3M, Warszawa, 2019.
[6] Federal Aviation Administration: Pilot's Handbook of Aeronautical Knowledge.

Skyhorse Publishing, Oklahoma City, 2017.

[7] Herbert Gnaś: Historia dronów – od starożytności do projektów Tesli. Twoja Historia,

Poznań, 2022.

[8] Korneliusz Jarzębski: NodeMCU v2 - idealna płytka dla IoT. Dev Jarzębski, Gliwice,

2015.

[9] Michał Kurzela: Jak działają szczotkowe silniki DC? Budowa i pomiary. Damian

Szymański, Poznań, 2019.

[10] Opracowanie zbiorowe: Tak To Działa. Drony. Bizbi Media SA, Lipowo, Nr 1/2016.
[11] Oskar Pacelt: Prosto o Arduino IDE – co to jest?. Botland, Gola, 2021.
[12] PM: Śmigła do quadcoptera. PORTAL DRONY - STUDIO 5S, Warszawa, 2017.
[13] Ryszard Szymaniak: Moduł żyroskopu i akcelerometru MPU-6050. Elektronika

praktyczna, Warszawa, 2021.

[14] S.: (https://starter-kit.nettigo.pl/author/sebastian/) Regulatory PID na Arduino - wstęp. Starter kit, Warszawa, 2013.
[15] Ty Audronis: Drony wprowadzenie. Helion, Gliwice, 2015.

Internet:

[16] https://aeromind.pl/Budowa-drona-ccms-pol-52.html [dostęp: 31.01.2023 r.]

[17] http://zrobsobiedrona.blogspot.com/2014/06/2-budujemy-quadcopter-jak-to-

dziala.html (http://zrobsobiedrona.blogspot.com/2014/06/2-budujemy-quadcopter-jak-to-dziala.html) [dostęp: 31.01.2023 r.]

[18] https://rc-planeta.pl/4096-thickbox_default/smigla-gemfan-10x45-cwccw-black-

para-smigiel-1045.jpg (https://rc-planeta.pl/4096-thickbox_default/smigla-gemfan-10x45-cwccw-black-para-smigiel-1045.jpg) [dostęp: 31.01.2023 r.]

[19] https://abc-rc.pl/Podstawy-wiedzy-o-smiglach-modelarskich-blog-pol-

1542270254.html (https://abc-rc.pl/Podstawy-wiedzy-o-smiglach-modelarskich-blog-pol-1542270254.html) [dostęp: 31.01.2023 r.]

[20] https://abc-rc.pl/product-pol-6764-Silnik-ABC-Power-A2212-1000KV-2-3S-135W-

ciag-820g.html (https://abc-rc.pl/product-pol-6764-Silnik-ABC-Power-A2212-1000KV-2-3S-135W-ciag-820g.html) [dostęp: 31.01.2023 r.]

[21] https://dronemanya.com/pl/post/co-to-jest-regulator-predkosci

[dostęp: 31.01.2023 r.]

[22] https://www.gimmik.net/blog/dobor-regulatora-obrotow-silnika-esc-modeli-rc/

[dostęp: 31.01.2023 r.]

[23] https://a.allegroimg.com/s512/031c56/ece67ad646cbb8821fe7d0520616/REGULAT

OR-30A-40A-UBEC-5V-2A-2S-4S-7-4V-14-8V-RC-EAN-GTIN-18350100 (https://a.allegroimg.com/s512/031c56/ece67ad646cbb8821fe7d0520616/REGULAT%20OR-30A-40A-UBEC-5V-2A-2S-4S-7-4V-14-8V-RC-EAN-GTIN-18350100)

[dostęp: 31.01.2023 r.]

[24] https://dronavista.pl/pl/akcesoria/8028-kontroler-lotu-f4-1s-12a-aio-elrs-24g-

betafpv.html#mz-expanded-view-1086059022504 (https://dronavista.pl/pl/akcesoria/8028-kontroler-lotu-f4-1s-12a-aio-elrs-24g-betafpv.html) [dostęp: 31.01.2023 r.]

[25] https://how2electronics.com/measure-tilt-angle-mpu6050-arduino/

[dostęp: 31.01.2023 r.]

[26] https://farm8.staticflickr.com/7408/10979127516_775c5fe166_o.jpg

[dostęp: 31.01.2023 r.]

[27] https://i.dronemanya.com/%D0%91%D0%9A-

%D0%BC%D0%BE%D1%82%D0%BE%D1%80-inrunner-outrunner-bcfb0.png (https://i.dronemanya.com/%D0%91%D0%9A-%D0%BC%D0%BE%D1%82%D0%BE%D1%80-inrunner-outrunner-bcfb0.png)

[dostęp: 31.01.2023 r.]

[28] https://steemitimages.com/p/2gsjgna1uruvUuS7ndh9YqVwYGPLVszbFLwwpAYXa4c

jnbfxrw9ExfSUxdzvniw9ynCNCib37sJiidQoFmoknNTXyuV1VgxeqzaaRDJxoESCGRikD

U?format=match&mode=fit&width=640 (https://steemitimages.com/p/2gsjgna1uruvUuS7ndh9YqVwYGPLVszbFLwwpAYXa4cjnbfxrw9ExfSUxdzvniw9ynCNCib37sJiidQoFmoknNTXyuV1VgxeqzaaRDJxoESCGRikDU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) [dostęp: 31.01.2023 r.]

[29] https://image.ceneostatic.pl/data/products/93125258/i-redox-pakiet-li-pol-

2200mah-30c-3s-11-1v.jpg (https://image.ceneostatic.pl/data/products/93125258/i-redox-pakiet-li-pol-2200mah-30c-3s-11-1v.jpg) [dostęp: 31.01.2023 r.]

Temat pracy w języku polskim: Projekt i wykonanie bezzałogowego statku latającego w

oparciu o mikrokontroler ESP32

Temat pracy w języku angielskim: Design and implementation of an unmanned aerial

vehicle based on the ESP32 microcontroller

Słowa kluczowe: bezzałogowy statek latający, dron, wielowirnikowiec, multikopter, ESP32,

NodeMCU v2, ESP8266

Streszczenie:

Praca inżynierska opiera się na zaprojektowaniu oraz wykonaniu bezzałogowego

statku latającego w formie kwadrokoptera, z zastosowaniem mikrokontrolera z rodziny

ESP32. Część teoretyczna porusza temat zasady działania wielowirnikowców, a także

przedstawia podstawowe podzespoły z jakich są one zbudowane. Zostały tam omówione

zasady którymi kierowano się podczas doboru poszczególnych podzespołów. W dalszej

części skupiono się na oprogramowaniach komputerowych, które przyczyniły się do

zrealizowania projektu. W części poświęconej układowi sterowania zostały opisane aspekty

projektowania, a następnie wykonania układu elektrycznego, a także proces wykonywania

oprogramowania sterującego układem. Rozdział układ mechaniczny skupia się na

zaprojektowaniu oraz wykonaniu ramy, złożeniu wszystkich podzespołów w całość oraz

przeprowadzeniu testów wykonanego modelu. Finalne udało się wykonać częściowo

działający prototyp bezzałogowego statku latającego. Analiza wyników została omówiona

w podsumowaniu, a także części poświęconej testowaniu kwadrokoptera.

Summary:

The engineering thesis is based on the design and construction of an unmanned aerial

vehicle in the form of a quadrocopter, using a microcontroller from the ESP32 family. The

theoretical part concerns the principle of operation of multicopters, and also presents the

basic components from which they are built. The principles that guided the selection of

individual components were discussed there. Next, the computer software that

contributed to the project is described. The part devoted to the control system describes

the aspects of designing and then implementing the electrical system, as well as the process of creating software controlling the system. The mechanical layout chapter focuses on

designing and building the frame, putting all the components together, and testing the

finished model. Finally, a partially working prototype of the unmanned aerial vehicle was

created. The analysis of the results is discussed in the summary, as well as in the

quadrocopter test section.

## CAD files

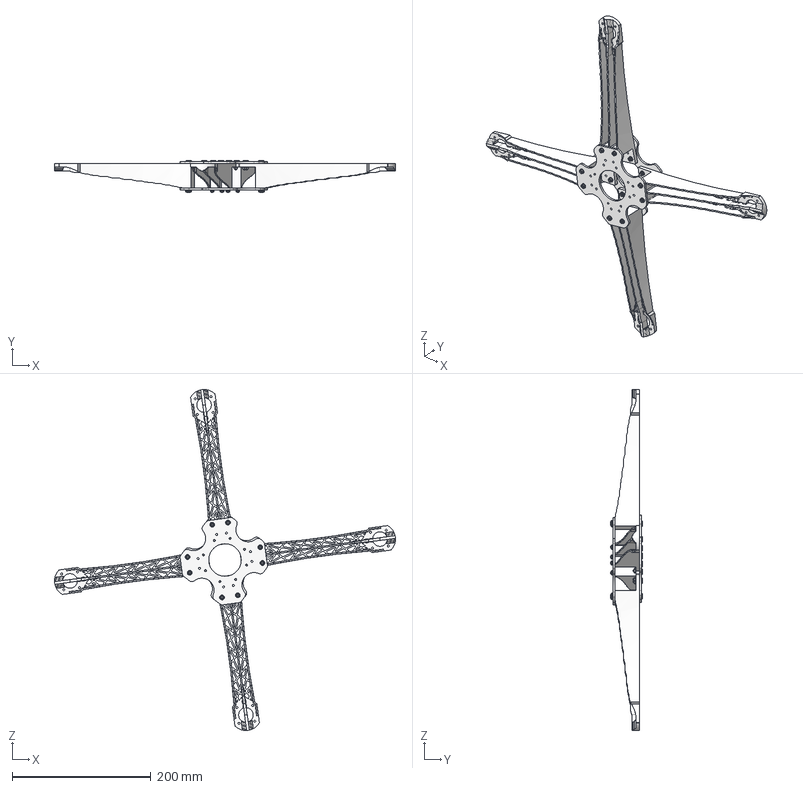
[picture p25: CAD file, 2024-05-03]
frame/frameAssembly.stp
492.4 x 46.6 x 492.4 mm
góra x 2
ramie x 4
ANSI B18.3.4M - M3 x 0.5 x 45, BHSBHCSM x 8
ISO 7089 - 3 x 16
ISO 4032 - M3 x 16
BS 4168 - M3 x 12 x 8

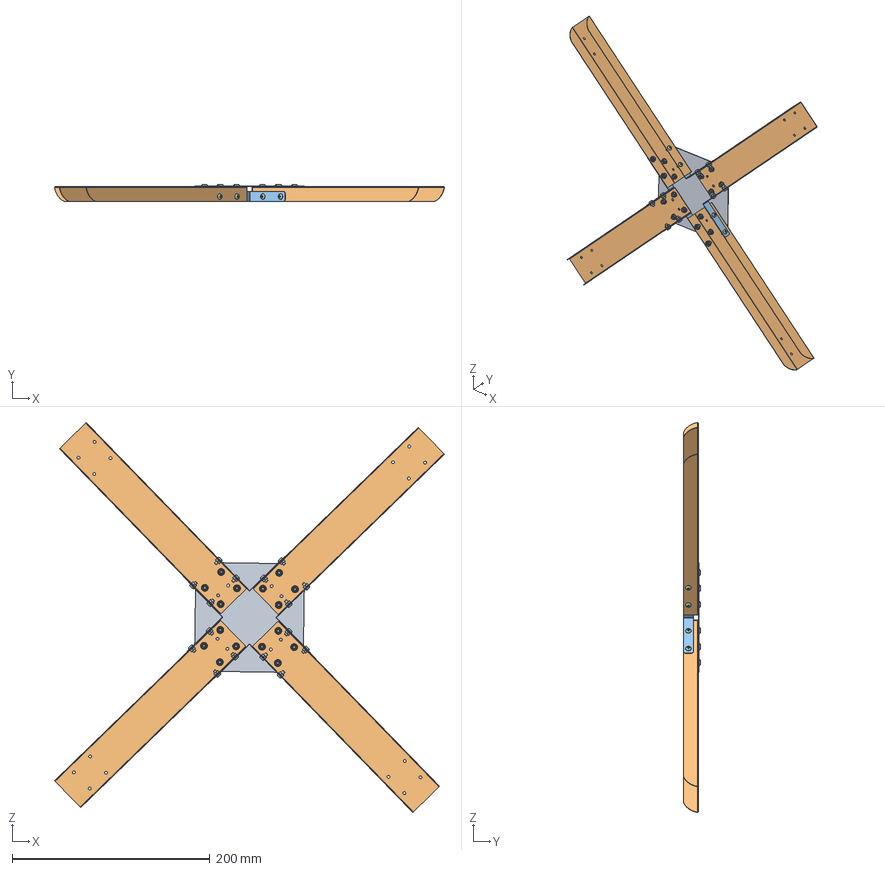
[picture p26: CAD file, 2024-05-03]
prototypeFrame/prototypeFrameAssembly.stp
394.4 x 17.2 x 394.4 mm
ŚrodejDronBlecha
RamieDronBlacha x 4
KątownikDronBlacha x 4
BS 4168 - M3 x 6 x 32
ISO 7089 - 3 x 32
ISO 4032 - M3 x 32

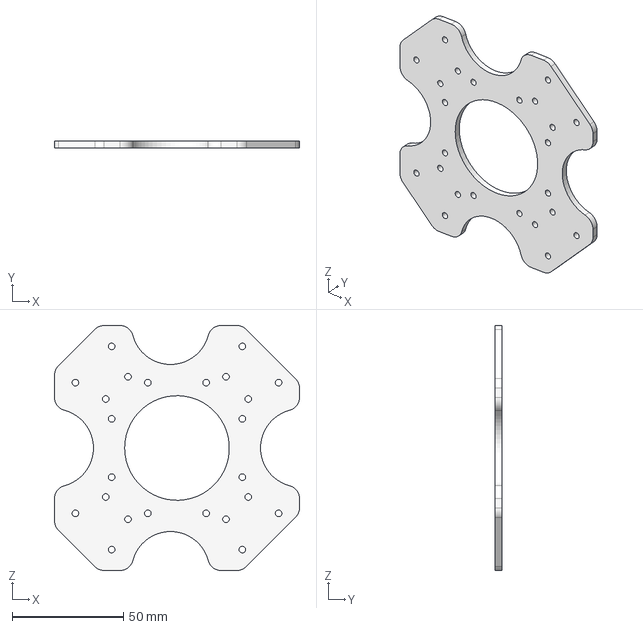
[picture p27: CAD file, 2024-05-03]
frame/plate.stp
110.0 x 3.00 x 110.0 mm

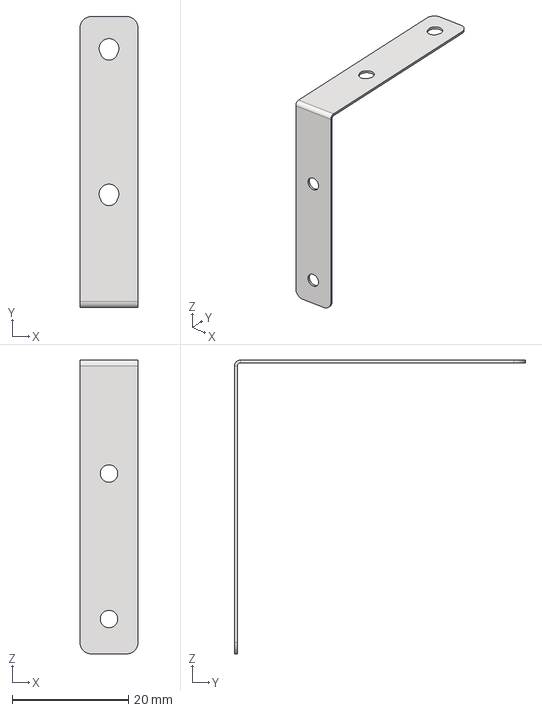
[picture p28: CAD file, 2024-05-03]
prototypeFrame/prototypeLink.stp
10.0 x 50.0 x 50.5 mm

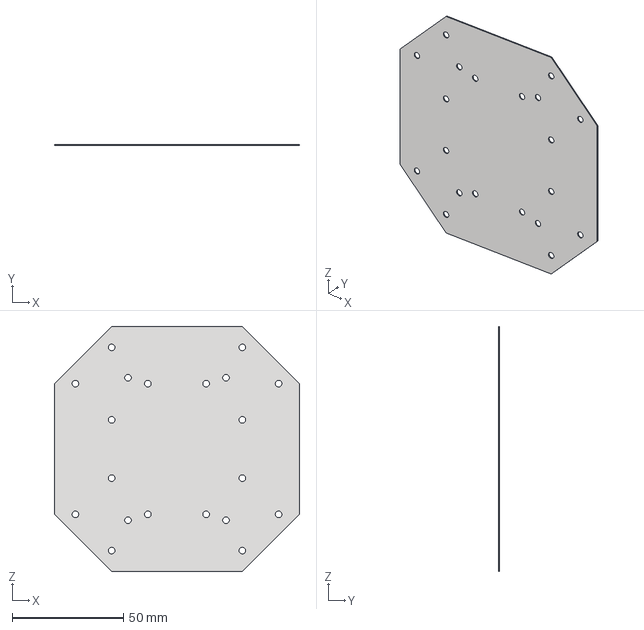
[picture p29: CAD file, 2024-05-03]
prototypeFrame/prototypePlate.stp
110.0 x 0.5 x 110.0 mm

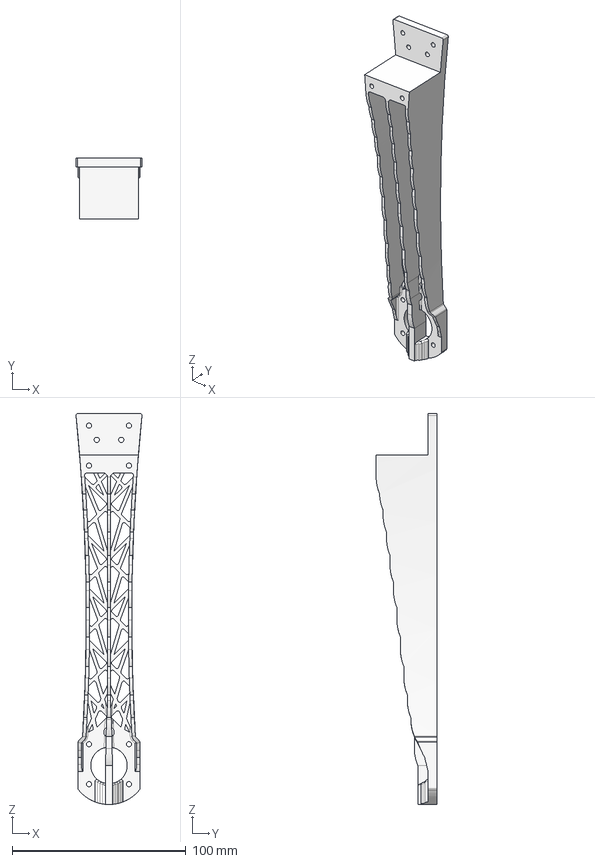
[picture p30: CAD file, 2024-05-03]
frame/arm.stp
38.0 x 35.0 x 225.2 mm

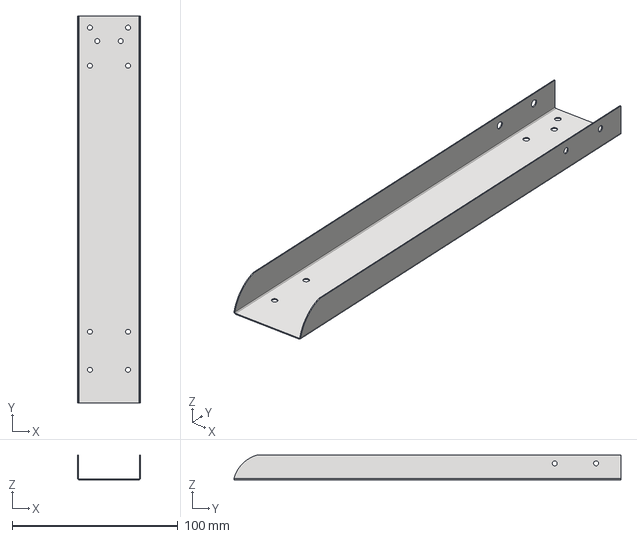
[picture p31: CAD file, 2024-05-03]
prototypeFrame/prototypeArm.stp
38.0 x 233.5 x 15.0 mm
